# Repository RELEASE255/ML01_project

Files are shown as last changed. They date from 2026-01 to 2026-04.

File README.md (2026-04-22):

# ML01 project by Greg
**DIY LED Board Powered by Raspberry Pico 2W**







<p align="center">
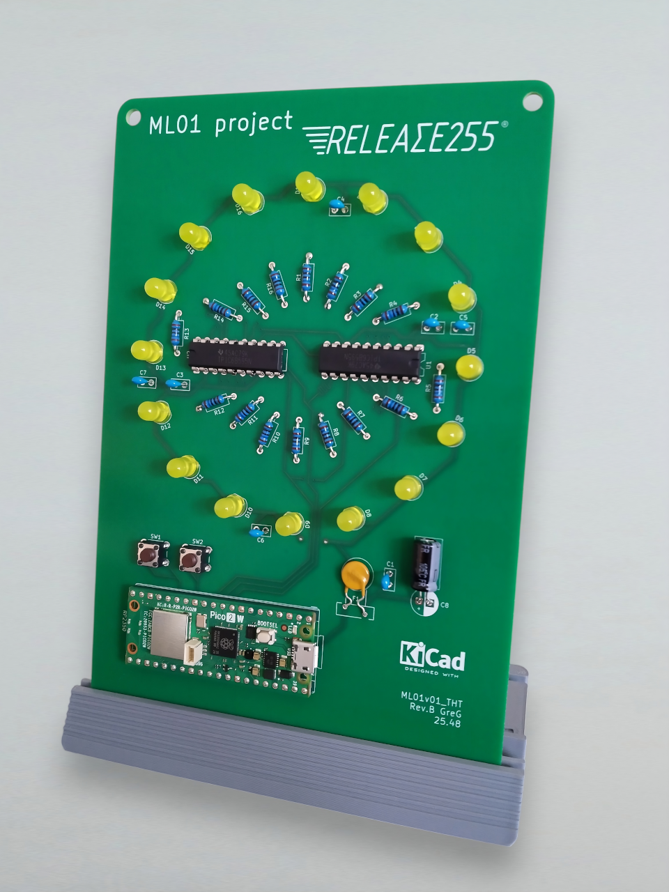
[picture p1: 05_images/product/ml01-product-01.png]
<br>
<sub>ML01 Main image</sub>
</p>

---

# 💡 Overview

**ML01** is a fully DIY through-hole LED board driven by a **Raspberry Pi Pico 2W** and two **TPIC6B595** shift registers. Built for makers, learners, and electronic enthusiasts, this product combining:

- Electronics learning
- Soldering practice
- Microcontroller programming
- Wireless control via Microdot
- Possibility to customize the firmware and hardware
- Open hardware philosophy with protected PCB design

---

# 📋 Key Features

- **LED Circle** | 16 yellow LEDs driven by 2× TPIC power shift registers
- **Physical Controls** | 2 buttons to switch operating modes
- **Wireless Web Interface** | Autonomous Microdot server for full remote control
- **Mode 1 (FULL)** | Turn all LEDs on 
- **Mode 2 (CHASE)** | Minute indicator synchronized via an NTP server
- **100% DIY THT** | Perfect for beginners and maker who wish to assemble or repair their product
- **Upgradable Firmware** | New modes and features can be added anytime
- **Easy Powered** | Works with the included 12.5 W PSU or via USB
- **Budget Friendly** | Transparent and moderate costs coupled with low consumption (~1 Wh)

---

# 📦 Contents of the Kit

**Available on Tindie (coming soon):**
- 01x PCB  

**To be purchased separately:**
- 01x Raspberry Pi Pico 2W (THT version)
- 01x Raspberry power supply 12.5 W (5.1 V / 2.5 A)
- 02x TPIC6B595 (Power Shift Register)
- 16x Yellow LED (2500 mcd 60 deg)
- 16x Metal resistors 160Ω 
- 07x Ceramic capacitor (X7R 100 nF)
- 01x Electro radial capacitor (100µF)
- 01x Resettable fuse
- 02x Push buttons  

**To be printed according to the provided 3D model:**
- 01x PCB stand
<br>

<p align="center">
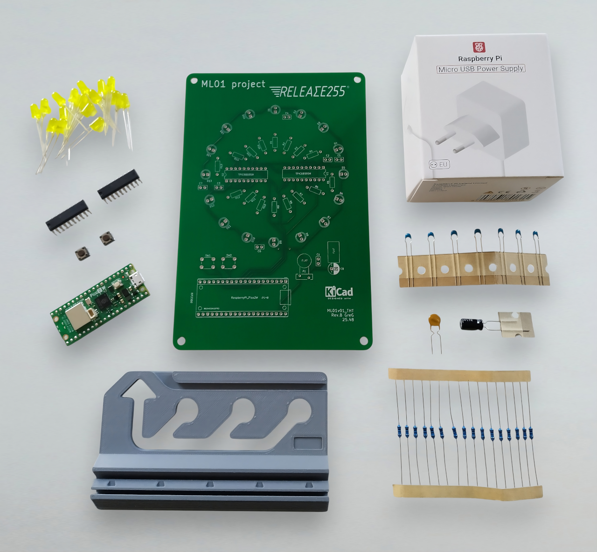
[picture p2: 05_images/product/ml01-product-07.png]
<br>
<sub>Complete DIY kit packaging</sub>
</p>

---

# 📸 Gallery

<p align="center">
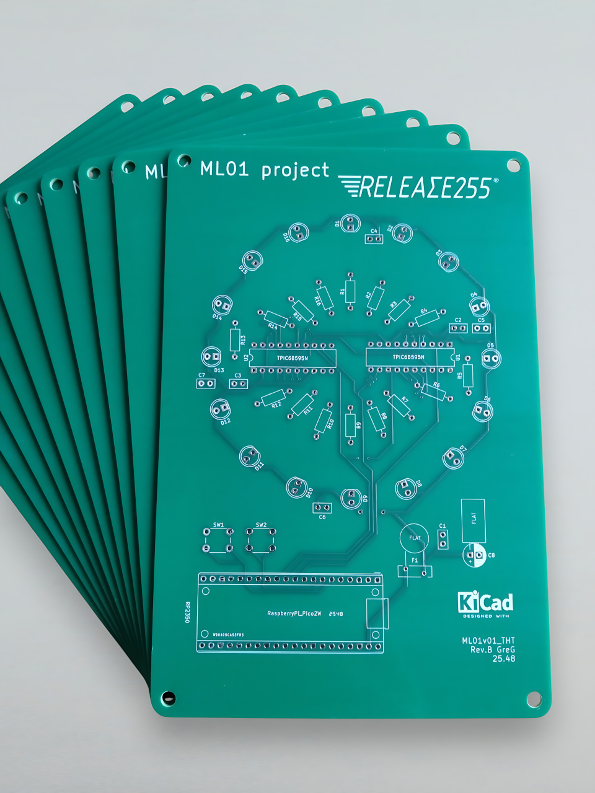
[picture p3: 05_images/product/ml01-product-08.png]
  <br>
<sub>Bare PCB front view</sub>
</p>

<p align="center">
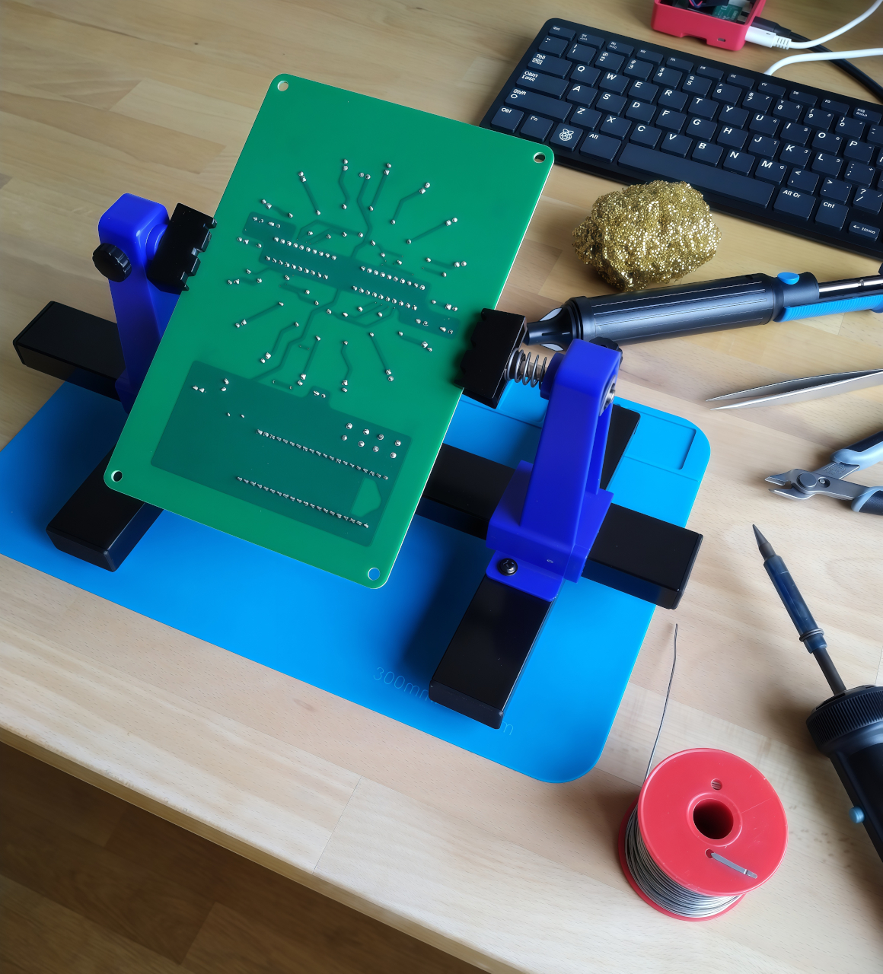
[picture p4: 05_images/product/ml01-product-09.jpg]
  <br>
<sub>DIY soldering THT components</sub>
</p>

<p align="center">
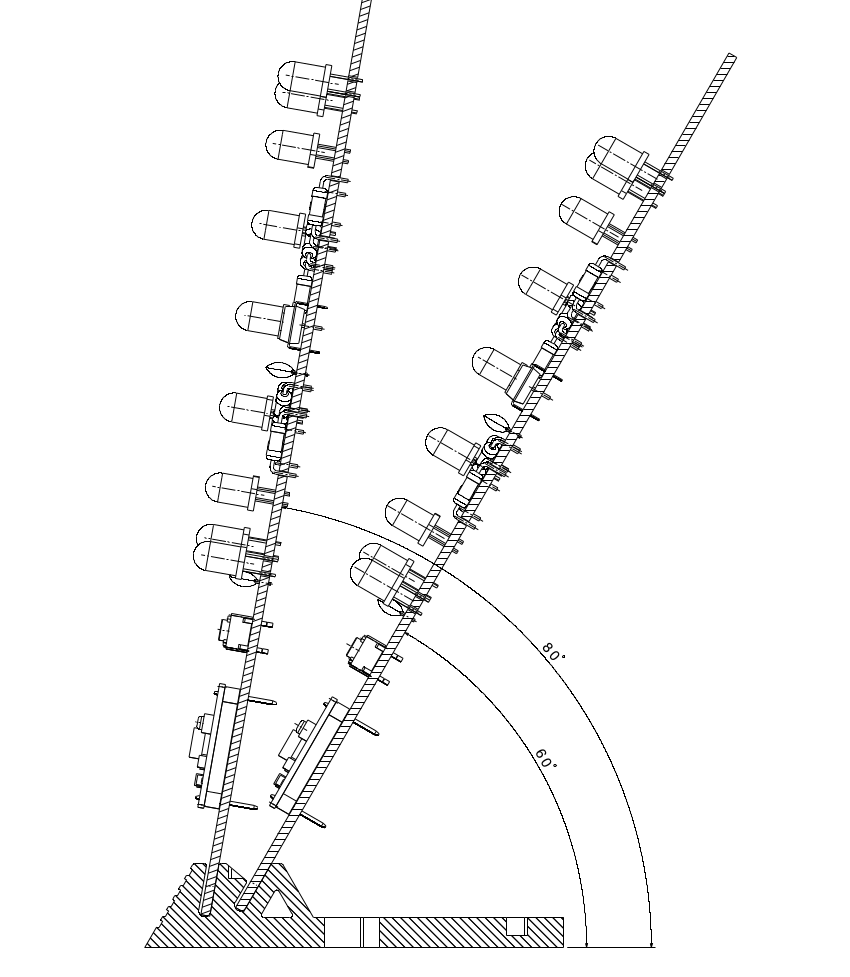
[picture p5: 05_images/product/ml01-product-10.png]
  <br>
<sub>Choice of orientation on the stand</sub>
</p>

<p align="center">
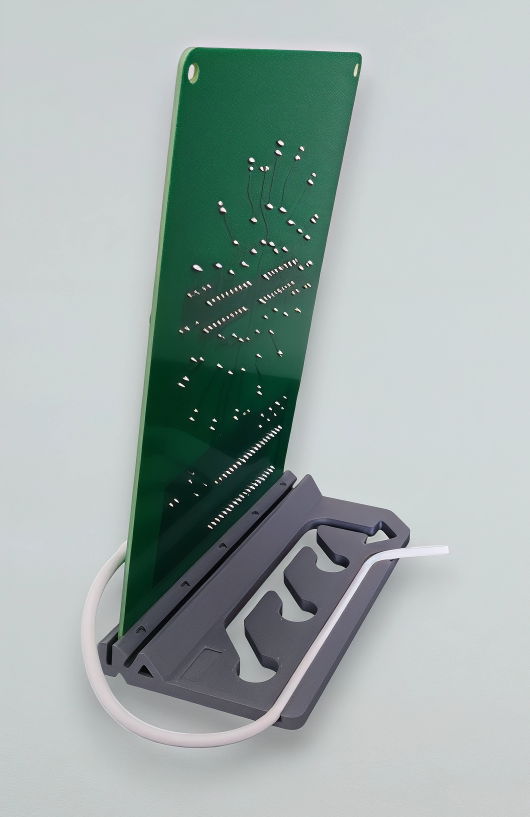
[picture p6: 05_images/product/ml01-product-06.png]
  <br>
<sub>PCB stand with cable holding</sub>
</p>

<p align="center">
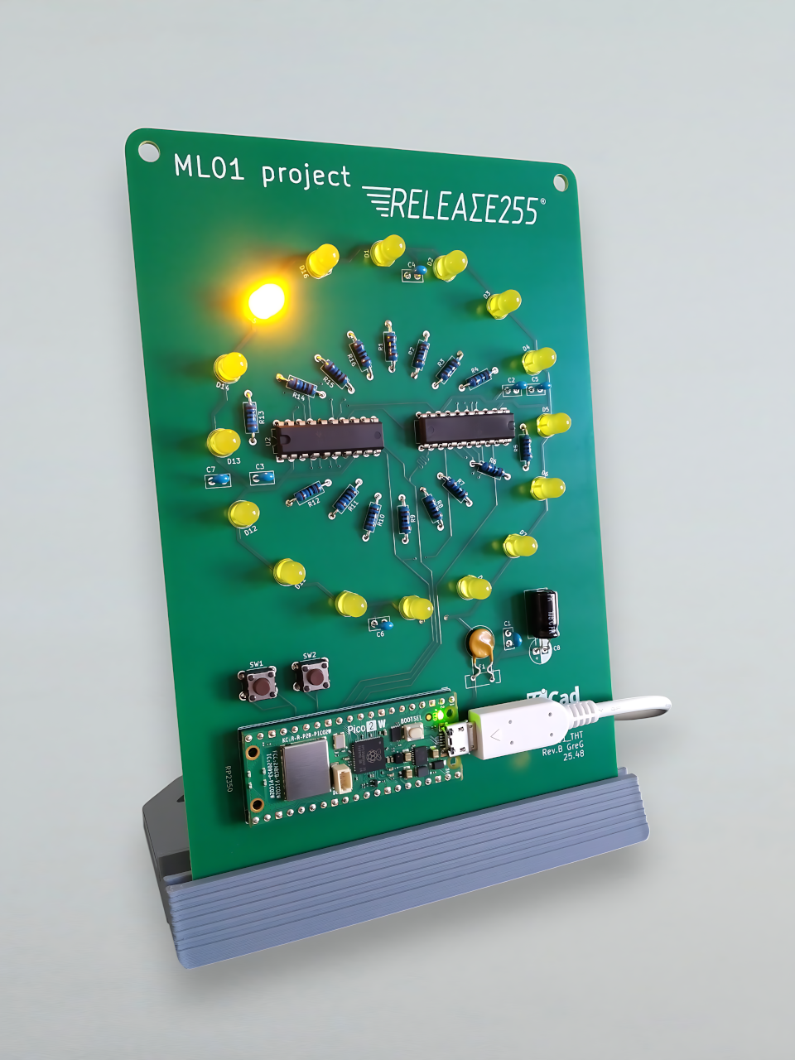
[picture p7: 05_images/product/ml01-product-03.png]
  <br>
<sub>CHASE mode activated</sub>
</p>

<p align="center">
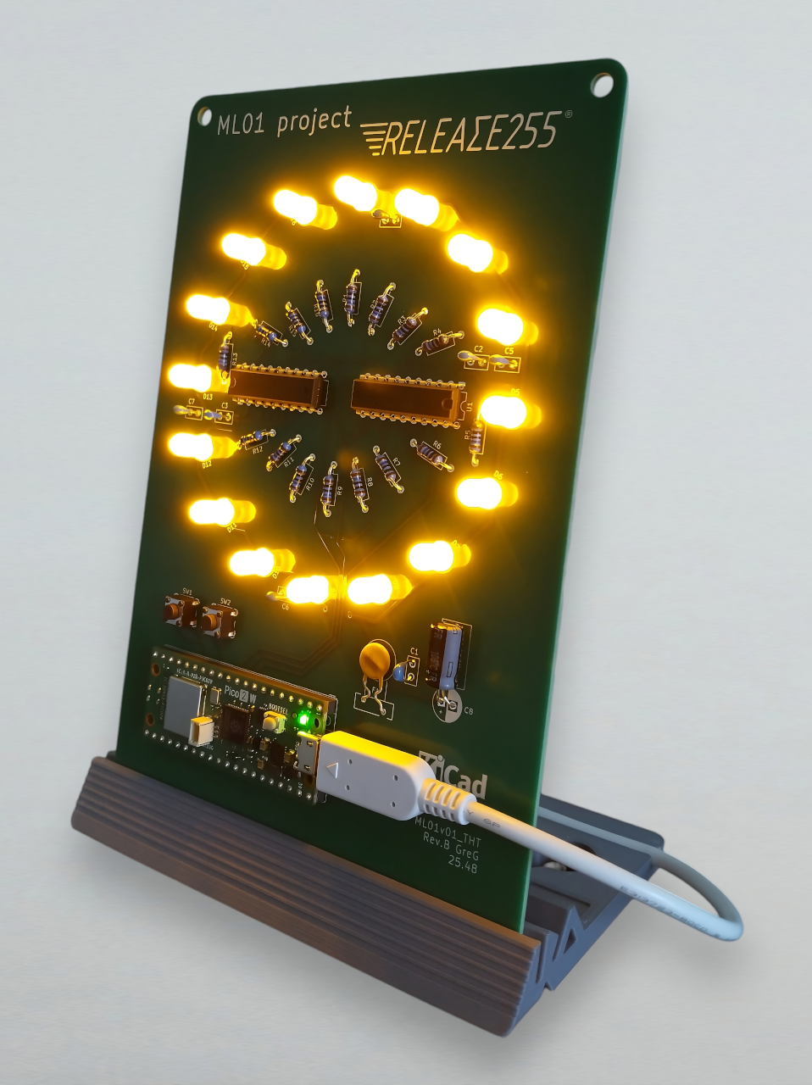
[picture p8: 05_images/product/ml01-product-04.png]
  <br>
<sub>FULL mode activated</sub>
</p>

<p align="center">
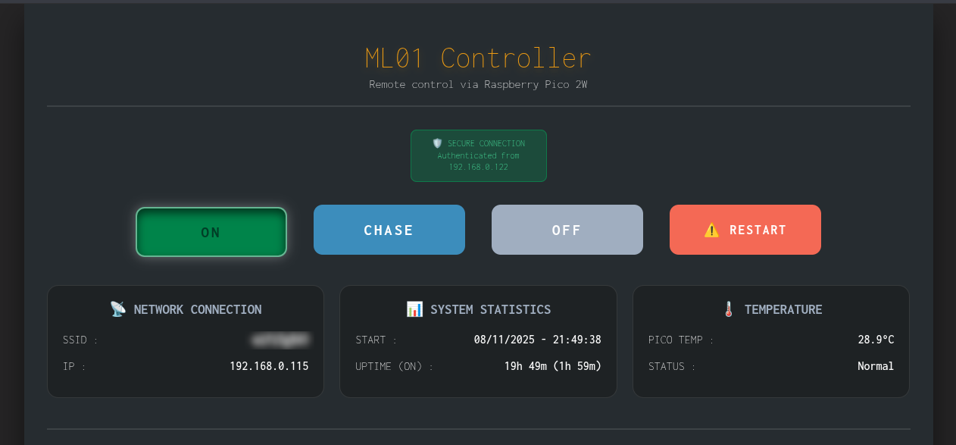
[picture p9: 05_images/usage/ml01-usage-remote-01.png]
  <br>
<sub>Web interface for remote control</sub>
</p>

<p align="center">
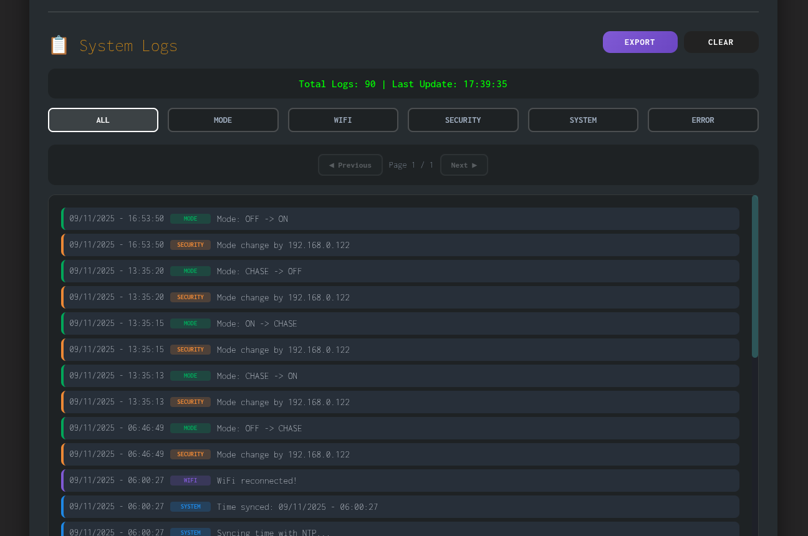
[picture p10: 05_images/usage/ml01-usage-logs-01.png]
  <br>
<sub>Web interface for log monitoring</sub>
</p>

<p align="center">
  ML01 CHASE mode animation<br>
  <sub>CHASE mode animated</sub>
</p>

---

# 📚 Documentation

## Specifications
See the document [Specifications](01_docs/ML01-specifications.md)

## Quick Start
1. **Solder** all components following the guide (⏱️ ~ 5 hours)
2. **Finishing** the PCB assembly with the cleaning
3. **Flash** the firmware to your Pico 2W
4. **Configure** the main.py file as you wish
5. **Transfer** the 3 files (main.py, index.html, microdot.py) to your pico
6. **Plug** the device to start the programm, it connects to your WiFi network
7. **Control** via web interface or the buttons

## Assembly  
Follow the complet guide to [Assembly](01_docs/ML01-assembly.md)

## Configuration  
Follow the complet guide to edit [Settings](01_docs/ML01-settings.md)

## Control & consult logs
Using the 2 physical buttons or the web interface, see the document [Usage](01_docs/ML01-usage.md)

---

# ⚠️ Disclaimer

- This is a **DIY kit requiring soldering**
- Assembly mistakes may damage components
- No warranty is provided
- Use at your own risk
- This device is intended for personal, non-commercial use only
  
**It has not been tested or certified to meet:**
- CE electromagnetic compatibility standards
- FCC Part 15 regulations
- RoHS compliance (components should be RoHS-compliant when sourced)

---

# 🌐 Ecosystem

- **3d stand:** *https://www.printables.com/model/1552197-pcb-stand*

# 💶 Buy the PCB

Feel free to contact me if this project interests you and you would like to purchase the printed circuit board.

---

# 📜 License Overview

ML01 uses a **multi-license** & **balanced open source model.**  
The main license is MIT but other parts of the project use Creative Commons licenses.  
Below is the complete list of licenses used in the repository.  
If you have any question about licensing or permitted uses, contact the project maintainer.

| Category | License | File Types | Commercial use | Full text |
|---|---|---|---|---|
| Firmware | MIT | `.py` `.html` | ✅ Allowed | [LICENSE](LICENSE) |
| BOM | CC BY-SA 4.0 | `.pdf` | ✅ Allowed | [LICENSE](03_hardware/LICENSE-bom.md) |
| Documentation | CC BY-NC-SA 4.0 | `.pdf` `.md` | 🚫 Not allowed | [LICENSE](01_docs/LICENSE-docs.md) |
| Technical plans | CC BY-NC-SA 4.0 | `.pdf` | 🚫 Not allowed | [LICENSE](03_hardware/LICENSE-hardware.md) |
| Schematics | CC BY-NC-SA 4.0 | `.pdf` | 🚫 Not allowed | [LICENSE](03_hardware/LICENSE-hardware.md) |
| 3D Models | CC BY-NC-SA 4.0 | `.stl` `.stp` | 🚫 Not allowed | [LICENSE](04_3dmodels/LICENSE-3dmodels.md) |
| Images | CC BY-NC-SA 4.0 | `.png` `.jpg` | 🚫 Not allowed | [LICENSE](05_images/LICENSE-images.md) |
| PCB Sources | Proprietary | Kicad & Gerbers | ❌ Not available | N/A |

### 🔒 PCB sources remain proprietary

In order to preserve the value of the design, guarantee independence, sustainability and the protection of creators, the following elements are not available:

- KiCad source files
- PCB routing & layout
- Gerber files
- 3D model of the actual PCB

### Third-Party Dependencies and Licenses

The ML01 firmware uses two essential external components:

#### **MicroPython**
ML01 runs on MicroPython, a Python interpreter optimized for microcontrollers.
- **License MIT**
- **Author:** Damien P. George and contributors
- **Official website:** https://micropython.org
- **Full text license:** [here](02_firmware/LICENSE-micropython.md)  
ℹ️ The firmware provided in this repository may not necessarily be the latest version.

#### **Microdot**
Microdot is an ultra-lightweight web micro-framework used for the ML01 kit's HTML interface.
- **License MIT**
- **Author:** Miguel Grinberg
- **Official Repository:** https://github.com/miguelgrinberg/microdot
- **Full text license:** [here](02_firmware/LICENSE-microdot.md)  
ℹ️ The `microdot.py` file provided in this repository may not necessarily be the latest version.

---

# 🤝 Contributions & Collaboration

Contributions to the **firmware** and **documentation** are welcome!

- Open issues for bugs, ideas, or improvements
- Submit pull requests for code or docs
- Proprietary files cannot be modified

### Interested in partnering?
I'm open to collaborations with:

- Makers
- Hardware designers
- Open-source communities

Let's explore cross-promotion, joint tutorials, shared tools, or group orders.

---

# 🗂️ Repository Structure

```
ML01/
├── 01_docs/
│   ├── LICENSE-docs.md
│   ├── ML01-assembly.md
│   ├── ML01-costs.pdf
│   ├── ML01-settings.md
│   ├── ML01-specifications.md
│   └── ML01-usage.md
│
├── 02_firmware/
│   ├── LICENSE-firmware.md
│   ├── LICENSE-microdot.md
│   ├── LICENSE-micropython.md
│   ├── RPI_PICO2_W-YYYYMMDD-vX.XX.X.uf2
│   ├── index.html
│   ├── main.py
│   └── microdot.py
│
├── 03_hardware/
│   ├── LICENSE-bom.md
│   ├── LICENSE-hardware.md
│   ├── ML01-bom.pdf
│   ├── ML01-drawingA3.pdf
│   └── ML01-kicad-schematic.pdf
│
├── 04_3dmodels/
│   ├── LICENSE-3dmodels.md
│   ├── ML01-pcbstand-v01.stl
│   └── ML01-pcbstand-v01.stp
│
├── 05_images/
│   ├── assembly/
│   ├── product/
│   ├── settings/
│   ├── usage/
│   └── LICENSE-images.md
│
├── CHANGELOG.md
├── CONTRIBUTING.md
├── LICENSE
└── README.md
```

*Revision date: 2026.04.22*<br>
© ML01 project by Greg | All rights reserved

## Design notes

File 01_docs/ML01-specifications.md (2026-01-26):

# ML01 PROJECT – SPECIFICATIONS
The ML01 project is an electronic system based on a **Raspberry Pi Pico 2W**.  
Its main role is to control **16 yellow LEDs** using 2 buttons and a lightweight embedded web interface using the Microdot framework.  
All components are Through-Hole Technology (THT) and require assembly onto a printed circuit board (DIY).  
<br>
⚠️ **LIMITATIONS AND WARNINGS** ⚠️
- **Indoor use only**
- **Not CE/FCC certified** | Hobbyist/educational use only
- **DIY assembly required** | Soldering skills necessary
- **Open PCB design** | Avoid contact with conductive materials
- **ESD sensitive** | Handle with antistatic precautions
- **No over-voltage protection** beyond PTC fuse
- **Wi-Fi stability** depends on local environment and interference
- **Safety Precautions while the device is powered:** thank you for reading the details at the end of this document.

**The following guides are provided in separate documentation files:**
- 📖 [ASSEMBLY guide](../01_docs/ML01-assembly.md)  
- 📖 [SETTINGS guide](../01_docs/ML01-settings.md)  
- 📖 [USAGE guide](../01_docs/ML01-usage.md)
---

## A. FUNCTIONS
### A1. LED modes by default
- **FULL mode:** all 16 LEDs ON continuously
- **CHASE mode:** dynamic LED animation sequence synchromnized with Time NTP server
- **OFF mode:** all LEDs OFF  
- **OTHER modes:** also you could completely reprogram the microcontroller according to your needs.

### A2. User Button Actions
**Button 1:**
- **Short press:** cycle through modes → FULL → CHASE → OFF
- **Long press:** stop script execution

**Button 2:**
- **Long press:** system reboot

### A3. Web Interface (Microdot):
- Lightweight HTTP server running on Raspberry Pi Pico 2W
- Default port: **5000**
- Provides remote access to LED modes, system status, and log viewing-exporting
- Requires Wi-Fi connection (SSID/password configured in firmware)
---

## B. HARDWARE
### B1. Main Controller: 1× Raspberry Pi Pico 2W RP2350 (THT variant)
- Handles GPIO control, timing, LED driving logic, and web server
- Powered via VSYS (pin 39) from external PSU or USB

### B2. Output Driving: 2× TPIC6B595N power shift registers
- 8 open-drain DMOS outputs per chip
- Up to 150 mA continuous current per output
- Daisy-chain capable (SER OUT → SER IN)
- VCC: +5V, logic-compatible with 3.3V GPIO

### B3. Optoelectronics: 16× yellow LEDs
- High efficiency
- Low power consumption
- Dimension: 5mm round standard
- Brightness: 2500 mcd typical
- Viewing angle: 60°
- Forward voltage: 1.9 to 2.3V typical
- Maximum forward current: 30 mA

### B4. User Input: 2× push buttons (6×6 mm, 1.6 N travel)
- Button 1: GPIO 4
- Button 2: GPIO 5
- Internal pull-ups enabled in firmware

### B5. Power Conditioning
**16× 160 Ω metal-film resistors (1% 0.6 W):** current limiting for LEDs (~18 mA per LED)

**7× 100 nF ceramic capacitors (X7R, 10% tolerance):**
- 1× per TPIC6B595N
- 4× near LED clusters
- 1× parallel to main electrolytic capacitor

**1× 100 µF electrolytic capacitor (Ø6.30 mm, H11.20 mm):** main power input filtering (+5V to GND)

**1× resettable PTC fuse (Bourns MF-R050):**
- Hold current: 0.5 A
- Trip current: 1.0 A
- Max voltage: 30 V
- Power rating: 750 mW
- Resistance: 770 mΩ

### B6. Power Input
| PARAMETER | VALUE |
|---|---|
| Voltage | 5 V DC |
| Current (FULL mode) | ~260 mA (1.3 W) |
| Current (OFF mode)  | ~35 mA (0.18 W) |
| Protection | PTC resettable fuse (0.5 A hold / 1 A trip) |

### B7. Power Supply: 1x Raspberry Pi 12.7W Micro USB
- AC 100-240V 50/60Hz input
- DC 5.1V 2.5A output
- 12.7W maximum output power
- 1.5m 18AWG captive cable
- Micro USB output connector
- Can alternatively be powered via USB port from computer.

### B8. LED Driving
- Open-drain low-side switching via TPIC6B595
- LED anodes connected to +5 V
- LED cathodes connected to TPIC DRAIN outputs through 160 Ω resistors
- LED current per channel: ~18 mA @ 5V supply
- Calculation: (5V - 2.1V Vf) / 160Ω ≈ 18 mA

### B9. Decoupling Strategy
- 1x 100 nF ceramic capacitor on each TPIC6B595N (VCC to GND)
- 4× 100 nF ceramic capacitors distributed near LED clusters
- 1× 100 nF ceramic capacitor in parallel with electrolytic capacitor at main power input
- 1x 100 µF electrolytic capacitor in parallel with ceramic capacitor at main power input

### B10. PCB Specifications
| PROPERTY | VALUE |
|---|---|
| Dimensions | 165 × 110 mm |
| Thickness | 1.6 mm |
| Layer Count | 2 |
| Copper Weight | 1 oz (35 µm) |
| Surface Finish | HASL lead-free |
| Solder Mask Color  | Green |
| Component Mounting | Through-Hole (THT) |
---

## C. WIRING
### C1. GPIO Pin Mapping for Raspberry Pi Pico 2W
| GPIO PIN | FUNCTION | CONNECTION |
|---|---|---|
| GPIO 4 | Button 1 Input | Push button (active LOW) |
| GPIO 5 | Button 2 Input | Push button (active LOW) |
| GPIO 7 | TPIC SER IN | Serial data to first TPIC |
| GPIO 8 | TPIC RCK | Register clock (both) |
| GPIO 9 | TPIC SRCK | Shift register clock (both) |

### C2. TPIC6B595N Pin Mapping
**First TPIC (chain input):**
| PIN | CONNECTION |
|---|---|
| Pin 1, 20 | Not used |
| Pin 2 (VCC) | +5V (Pico pin 39, VSYS) |
| Pin 3 (SER IN) | Pico GPIO 7 |
| Pins 4-7(DRAIN 0-3) | LED cathodes via 160Ω resistors |
| Pin 8 (SRCLR) | +5V (reset disabled, always HIGH) |
| Pin 9 (G) | GND (outputs always enabled, active LOW) |
| Pin 10, 11, 19 (GND) | Pico GND (pin 3) |
| Pin 12 (RCK) | Pico GPIO 8 |
| Pin 13 (SRCK) | Pico GPIO 9 |
| Pins 14-17 (DRAIN 4-7) | LED cathodes via 160Ω resistors |
| Pin 18 (SER OUT) | Pin 3 (SER IN) of second TPIC |

**Second TPIC (chain output):**  
Same connections as first TPIC apart from the differences below:
- Pin 3 (SER IN) ← Pin 18 (SER OUT) of first TPIC
- Pin 18 (SER OUT) → not connected

### C3. LEDs Connections
- **LED anodes** → +5 V (common rail)
- **LED cathodes** → TPIC DRAIN outputs via 160 Ω resistor

### C4. Buttons Connections
- **Button 1** → One pin to GPIO 4 (Pico pin 6), other pin to GND
- **Button 2** → One pin to GPIO 5 (Pico pin 7), other pin to GND
- Internal pull-up resistors enabled in firmware (buttons active LOW)
---

## D. SOFTWARE
### D1. Firmware (MicroPython for Raspberry Pi Pico 2W RP2350)
- Download last version UF2 bootloader image [here](https://micropython.org/download/RPI_PICO2_W/)
- Flash via USB mass storage mode

### D2. Program Structure
- `main.py`: main control program, download last version [here](../02_firmware/)
- `index.html`: web interface for remote control and log viewing/exporting, download last version [here](../02_firmware/)
- `microdot.py` : lightweight web server, download last version [here](https://github.com/miguelgrinberg/microdot)

### D3. Dependencies and References
- [Raspberry Pi Pico 2W](https://www.raspberrypi.com/documentation/microcontrollers/)
- [TPIC6B595N Datasheet](https://www.ti.com/lit/ds/symlink/tpic6b595.pdf)
- [MicroPython](https://docs.micropython.org/en/latest/)
- [Microdot](https://microdot.readthedocs.io/en/latest/index.html#)
---

## E. ENCLOSURE CONSIDERATIONS (to be printed according to provided 3D files)
**This is an open PCB design:**
- The PCB stand allows 2 possible tilt angles: 80° and 60°.
- The PCB stand must be printed according to the file provided on this repo [here](../04_3dmodels/) or Printables [here](https://www.printables.com/model/1552197-pcb-stand)
- The ML01 project deliberately does not include a fully enclosed protective case at this stage.
- This design choice allows all electronic components to remain visible, which is valuable for:  
        - Educational purposes and learning electronics<br>
        - Demonstrating the circuit layout and component placement<br>
        - Aesthetic appreciation of the assembled board

⚠️ **Safety Precautions while the device is powered:**
- **Do NOT touch** any part of the PCB except the two push buttons
- Risk of **electric shock** from exposed 5V circuitry
- Risk of **short circuits** causing component damage or failure
- Risk of **ESD damage** to sensitive components (Pico 2W, TPICs)

**This device is fragile:**
- Solder joints and component leads can break with rough handling
- Through-hole components are more robust than SMD but still require care
- Use the provided 3D-printed stand to minimize handling

**Indoor use only:**
- Indoor use in dry, controlled environments (typical household/office: 30–60% RH)
- Not rated for outdoor or humid environments (no conformal coating)
- Keep away from water, liquids, and excessive moisture
- Avoid dusty or dirty environments that could cause short circuits

**Recommended operating environment:**
- Recommended ambient: 15–30°C for optimal long-term reliability (mini 0°C to max 70°C)
- Keep away from direct sunlight to prevent overheating
- Workbench or desk in a clean (avoid directly on the ground)
- Display area with controlled access (away from children and pets)

**Future Enclosure Options:**
- A protective enclosure may be offered in future revisions of this project if the need is actually confirmed.
- Users who require additional protection may design their own enclosure, ensuring adequate ventilation for heat dissipation.
---

## F. COMPLIANCE AND STANDARDS
This device is intended for personal, non-commercial use only.  
Users are responsible for ensuring compliance with local regulations if used in any commercial capacity.  
<br>
**It has not been tested or certified to meet:**
- CE electromagnetic compatibility standards
- FCC Part 15 regulations
- RoHS compliance (components should be RoHS-compliant when sourced)
---

*Revision date: 2026.01.26*<br>
© RELEASE255 | All rights reserved

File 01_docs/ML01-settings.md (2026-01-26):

# ML01 PROJECT – SETTINGS GUIDE
This document guides you through the firmware installation and initial configuration of your ML01 device.

## A. PREREQUISITES
Before starting, ensure you have:  
✓ Fully assembled ML01 PCB (see 📖 [ASSEMBLY](../01_docs/ML01-assembly.md))  
✓ Micro-USB cable  
✓ 5.1V 2.5A power supply (for standalone operation after setup)  
✓ Computer running Linux, Windows, or macOS  
✓ Integrated development environment (IDE) such as Thonny with MicroPython interpreter  
✓ Internet connection (note that the Pico 2W is only compatible with a **2.4 GHz Wi-Fi network**)  
✓ Wi-Fi network with known SSID and password  
✓ Your computer's local IP address (instructions below)
###
---

## B. FLASH MICROPYTHON FIRMWARE TO RASPBERRY PICO 2W
⚠️ **This step is required before first use**
### B1. Download Firmware
- **01.** Visit https://micropython.org/download/RPI_PICO2_W/
- **02.** Download the latest stable release `.uf2` file.

### B2. Enter Bootloader Mode & Flash Firmware
- **01.** Locate the **BOOTSEL button** on the Raspberry Pi Pico 2W (small white button near the micro-USB connector).
- **02.** **Push and hold** the BOOTSEL button while connecting your Pico with a USB cable to your computer.
- **03.** **Release** the BOOTSEL button **once your Pico appears as a Mass Storage Device.**
- **04.** **Drag and drop** the MicroPython UF2 file onto the RPI-RP2 volume, your Pico will **automatically reboot.**
- **05.** **Wait** for the process to complete (~5 seconds).

### B3. Verify Firmware Installation
- **01.** **Disconnect** the Pico from your computer.
- **02.** **Reconnect** the Pico via micro-USB.
- **03.** Open your **IDE**.
- **04.** Make sure the Pico is recognized:  
        - With Thonny, check bottom-right corner.<br>
        - Should see "MicroPython (Raspberry Pi Pico)"<br>
        - If not, click the interpreter selector and choose it.<br>
- **05.** You should see the instructions below in the shell using Thonny editor:

<p align="center">
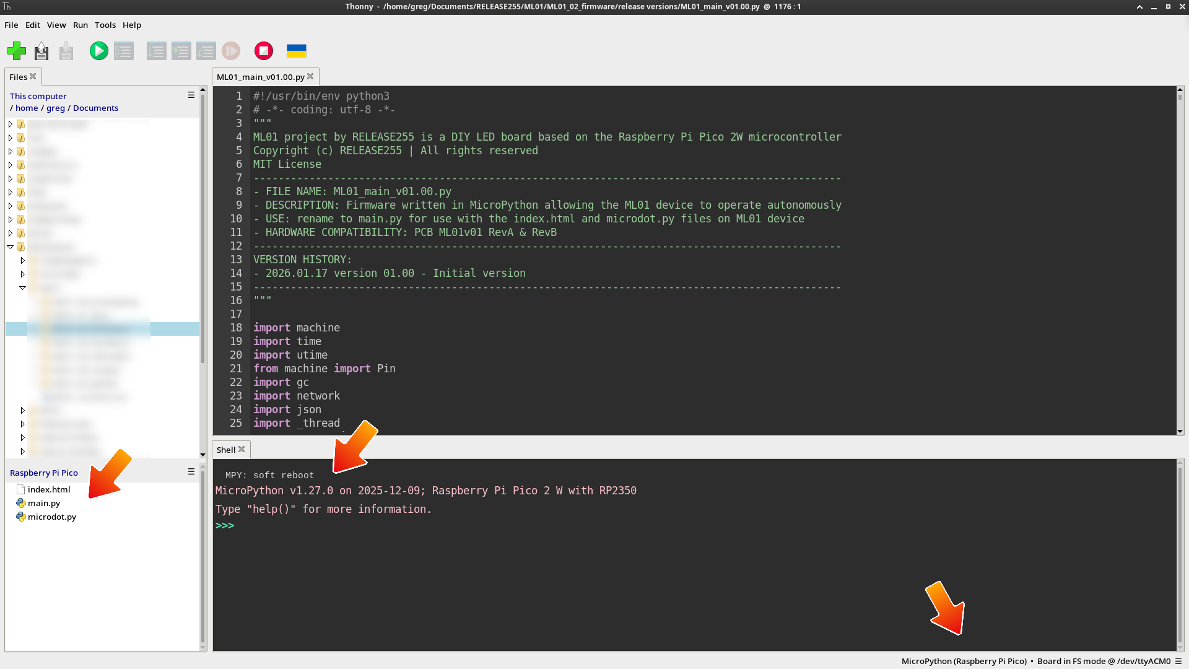
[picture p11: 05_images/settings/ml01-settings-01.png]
  
</p>

✅ **Firmware installation successful!**
###
---

## C. DOWNLOAD FIRMWARE FILES FROM GITHUB
Download the following three files from the `02_firmware/` folder [here](../02_firmware/):

```
02_firmware/
├── index.html      ← Web interface HTML file
├── main.py         ← Main control program
└── microdot.py     ← Lightweight web server library
```
---

## D. CONFIGURE main.py FILE
The `main.py` file contains all configuration parameters for your ML01 device.
### D1. Open main.py in Thonny
- **01.** In Thonny, click **File → Open...**
- **02.** Navigate to where you saved the firmware files.
- **03.** Open **main.py**.

### D2. Locate Configuration Section
- **01.** Press **Ctrl+F** (Windows/Linux) or **Cmd+F** (macOS) to open Find.
- **02.** Search for: `# CONFIGURATION`
- **03.** You should find the configuration section around **line 37** (may vary slightly):

<p align="center">
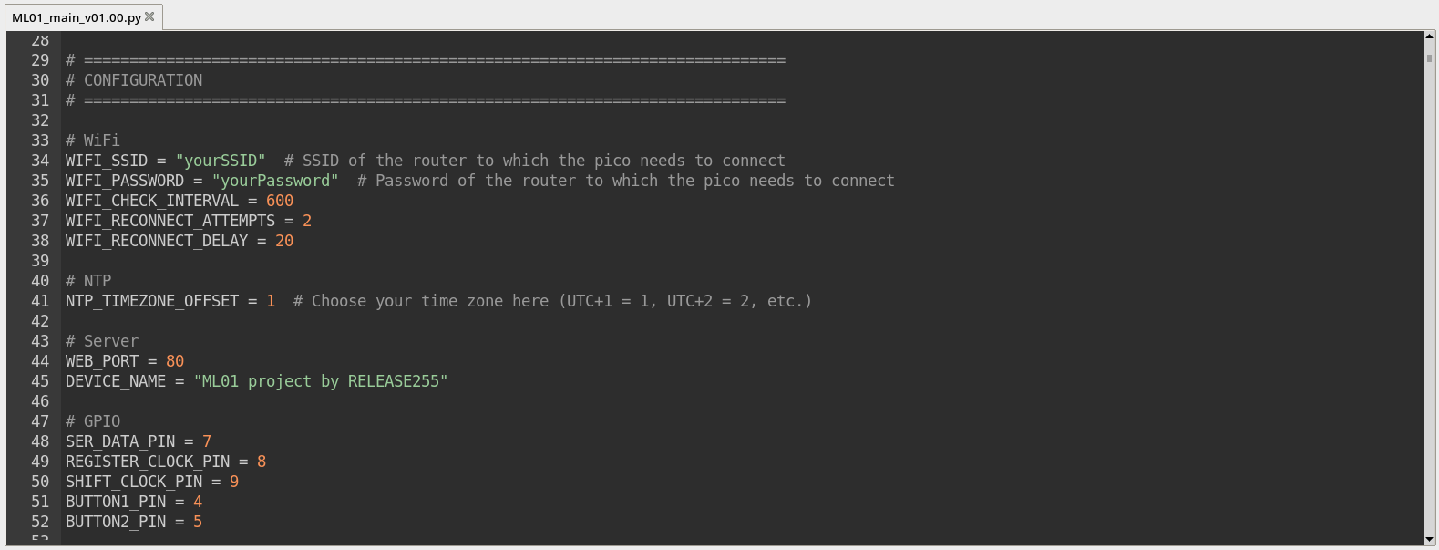
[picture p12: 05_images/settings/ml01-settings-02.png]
  
</p>

### D3. Configure Wi-Fi Settings
Locate the **WiFi** section:
```python
# WiFi
WIFI_SSID = "yourSSID"
WIFI_PASSWORD = "yourPassword"
```
- **01.** Replace `"yourSSID"` with your Wi-Fi network name.
- **02.** Replace `"yourPassword"` with your Wi-Fi password.

### D4. Configure Timezone (NTP)
Locate the **NTP** section:
```python
# NTP
NTP_TIMEZONE_OFFSET = 1
```
**Set your timezone offset relative to UTC, for example:**
| Location | Offset | Value |
|---|---|---|
| Seoul | UTC+9  | `9` |
| Taipei | UTC+8  | `8` |
| Bengaluru | UTC+5  | `5` |
| Zurich | UTC+1  | `1` |
| London | UTC+0  | `0` |
| Boston | UTC-5  | `-5`  |
| Palo Alto | UTC-8  | `-8`  |

**Note:** This does not account for Daylight Saving Time (DST). Adjust manually if needed.

### D5. Configure LED Timing (Optional)
Locate the **Timing** section:

<p align="center">
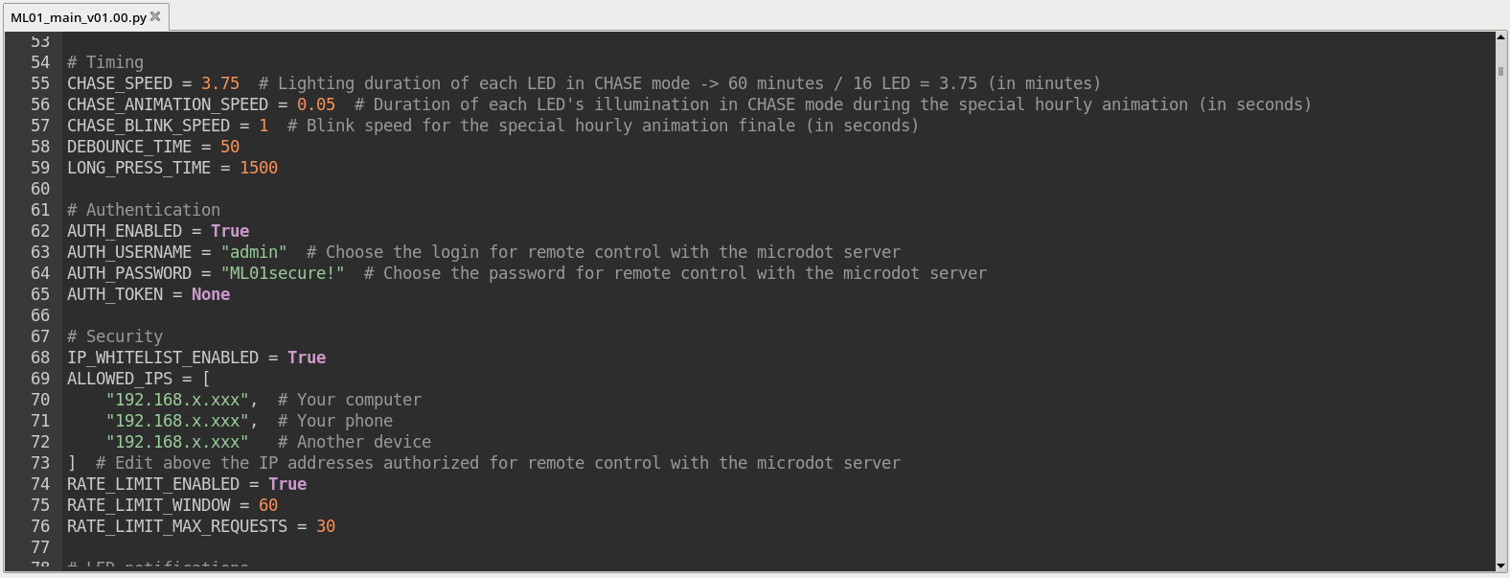
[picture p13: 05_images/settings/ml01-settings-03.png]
  
</p>

- **01.** `CHASE_ANIMATION_SPEED`: Adjust the value as needed  
        - Default: `0.05` (50ms per LED)
        - Lower = faster animation
        - Higher = slower animation
- **02.** `CHASE_BLINK_SPEED`: Adjust the value as needed  
        - Default: `1` (1 second on/off cycle)

### D6. Configure Web Authentication
Locate the **Authentication** section:
- **01.** `AUTH_ENABLED`: Controls whether web interface requires login.  
        - `True` = Login required (recommended)
        - `False` = Open access (not recommended on shared networks)
- **02.** `AUTH_USERNAME`: Choose a username for web interface access.  
        - Default `AUTH_USERNAME = "admin"`
- **03.** `AUTH_PASSWORD`: Choose a secure password for web interface access.  
        - Default `AUTH_PASSWORD = "ML01secure!"`

### D7. Configure IP Address Whitelist
Locate the **Security** section:  
```python
ALLOWED_IPS = [
    "192.168.1.100",  # Your computer
    "192.168.1.105",  # Your phone
    "192.168.1.110"   # Another device
]
```
- Find your computer's local IP address and replace placeholder IPs with actual addresses you want to allow.
- **Purpose:** Restricts web interface access to specific IP addresses on your local network.
- To disable IP filtering entirely **(not recommended):** set `AUTH_ENABLED = False`

⚠️ **Security Recommendation:**  
✓ Change default `AUTH_USERNAME` and `AUTH_PASSWORD`.  
✓ Use strong passwords (mix of letters, numbers, symbols).  
✓ Keep `AUTH_ENABLED = True` on shared networks.  
✓ Update `ALLOWED_IPS` if your network changes (DHCP).  
✓ Consider setting **static IP** for your devices in router settings.  
✓ If `AUTH_ENABLED = True` and `ALLOWED_IPS = []` (empty list), **no devices can connect**.  
✓ Do not expose Pico to public internet without additional security measures.  
✓ Regularly update MicroPython firmware for security patches.
###

### D8. Save Configuration
- **01.** Review all changes carefully.
- **02.** In Thonny, click **File → Save** (or press **Ctrl+S** / **Cmd+S**).
- **03.** Keep the file open in Thonny for the next step.
---

## E. UPLOAD FILES TO RASPBERRY PI PICO
### E1. Connect Pico to Computer
Connect your Raspberry Pi Pico 2W to your computer via micro-USB cable (if it hasn't already been done).

### E2. Upload main.py
- **01.** With `main.py` open and configured in Thonny, click **File → Save As...**
- **02.** In the dialog, select **"Raspberry Pi Pico"** as the destination.
- **03.** Name exactly the file: **`main.py`** (allows the program to start automatically when the Pico is connected to the power supply).
- **04.** Click **OK** to upload.

### E3. Upload microdot.py
Do the same thing as before, saving the **`microdot.py`** file in the pico

### E4. Upload index.html
Do the same thing as before, saving the **`index.html`** file in the pico

### E5. Verify Files on Pico
- **01.** In Thonny, look at the **Files panel** (usually on the left side).
- **02.** Under **"Raspberry Pi Pico"**, you should see:
```
/
├── index.html
├── main.py
└── microdot.py
```

<p align="center">
  
</p>

✅ **All files successfully uploaded!**
###
---

## F. VERIFY INSTALLATION
### F1. Run Initial Test
- **01.** In Thonny, ensure the **`main.py`** tab is active.
- **02.** Click the **green "Run" button** (▶) or press **F5**.
- **03.** Monitor the **Shell panel** at the bottom of Thonny.

### F2. Check Console Output
You should see output similar to:
```
======================================================================
ML01 LED CONTROLLER - PICO 2W
======================================================================

MODES:
• OFF: All LEDs off
• ON: All LEDs on
• CHASE: Sequential LED movement

CONTROLS:
• Button 1 short: Switch mode
• Button 1 long: Shutdown
• Button 2 long: Manual restart
• Web: http://[IP_ADDRESS]

LED NOTIFICATIONS:
• Solid: WiFi connected
• OFF: WiFi disconnected
• Fast blink: New connection
----------------------------------------------------------------------

Initializing security...
[SYSTEM] Auth enabled (user: admin)
✓ Auth: admin
✓ IP filter: 6 allowed
✓ Rate limit: 30/60s
Initializing GPIO...
GPIO initialized
[SYSTEM] ML01 Controller started
Connecting to WiFi...
[SYSTEM] Syncing time with NTP...
[SYSTEM] Time synced: 31/12/2025 - 09:19:46
✓ Time synced (UTC+1)
[SYSTEM] Start time updated after NTP
Starting web server thread...
[WEB] Thread started
[WEB] Free memory: 402880 bytes
[WEB] Starting on port 80...
[WEB] http://192.168.0.124:80
[SYSTEM] Web server on http://192.168.0.124
✓ Web: http://192.168.0.124
  Login: yourLogin / yourPassword
Starting with mode ON1

[MEMORY] Periodic check - Free: 400768 bytes (6 logs)
```
✅ **Key indicators of success:**  
✓ Time synced (UTC+..)  
✓ Web: http://192.168.0.124 (IP adress in the example)  
✓ Onboard green LED on Pico 2W is lit 🟩

### F3. Note Your Pico's IP Address
- **01.** Look for the line: `[WEB] http://192.168.0.xxx:80`
- **02.** **Write down this IP address** – you'll need it to access the web interface.

### F4. Test Physical Buttons
- **01.** Press **Button 1** (short press): LEDs should cycle through modes: FULL → CHASE → OFF
- **02.** Observe console output:
```
[MODE] Mode: ON -> CHASE
[CHASE] Starting animation to LED 9
[CHASE] Animation complete, LED 9 active
[MODE] Mode: CHASE -> OFF
[MODE] Mode: OFF -> ON
... 
```
- **03.** Press **Button 1** (long press ~3 seconds): Script should stop with message: "Script stopped by user"
```
Button 1 long press - shutting down...
GPIO cleaned

==========================================
FINAL STATISTICS
Started: 31/12/2025 - 09:39:16
Total ON time: xxm
==========================================
Program terminated
```
- **04.** Press **Button 2** (long press ~3 seconds): Pico should reboot (console will show restart sequence)
```
Button 2 long press - restarting...
[SYSTEM] Manual restart initiated

==================================================
RESTARTING...
==================================================
```
**Note:** The Thonny console correctly displays the "restartig sequence" but then loses the connection: this is normal operation.  
The device remains controllable with its buttons or via the web interface, but no longer via Thonny.

✅ **If buttons respond correctly, hardware is functioning properly.**
### 🎉 CONGRATULATIONS 🎉 Your ML01 device is now configured and ready to run independently.
---

## G. STANDALONE OPERATION
### G1. Disconnect from Computer
- **01.** In Thonny, click the **red "Stop" button** (■) to halt the running script.
- **02.** Close Thonny.
- **03.** **Disconnect** the Pico from your computer.

### G2. Connect to Power Supply
- **01.** Connect the **5.1V 2.5A micro-USB power supply** to the Pico.
- **02.** The **`main.py`** script will **automatically start** on boot.
- **03.** Wait 5-10 seconds for:  
        ✓ Wi-Fi connection to establish<br>
        ✓ Synchronization with the NTP server<br>
        ✓ Web server to start<br>
        ✓ LEDs to activate in default mode<br>

### G3. Confirm Auto-Start
- **01.** Check that **LEDs illuminate** (FULL mode by default).
- **02.** Check that **Pico onboard LED** is lit.

### G4. To access the web interface and control your ML01 remotely
See 📖 [USAGE](../01_docs/ML01-usage.md) to know how to use ML01 for daily operation and monitoring, this document covers:  
- LED OPERATING MODES
- PHYSICAL BUTTON CONTROLS
- ONBOARD LED INDICATOR (Pico LED)
- WEB INTERFACE ACCESS
- WEB INTERFACE FEATURES
- SYSTEM STATISTICS
---

## H. TROUBLESHOOTING
### H1. Thonny doesn't detect Pico
✓ Ensure micro-USB cable supports **data transfer** (not just charging).  
✓ Try a different USB port on your computer.  
✓ Restart Thonny and reconnect Pico.  
✓ Re-flash MicroPython firmware.

### H2. "WiFi connection failed" error
✓ Verify SSID and password are correct (case-sensitive).  
✓ Ensure Wi-Fi network is **2.4 GHz** (not 5 GHz).  
✓ Move Pico closer to Wi-Fi router.  
✓ Check if network has MAC address filtering (whitelist Pico's MAC).  
✓ Restart your router.

### H3. No IP address displayed
✓ Ensure Wi-Fi credentials are correct.  
✓ Check that router DHCP is enabled.  
✓ Try connecting Pico to a different Wi-Fi network for testing.

### H4. LEDs don't light up
✓ Verify power supply provides 5.1V and sufficient current (2.5A).  
✓ Check solder joints on LED connections (see assembly guide).  
✓ Test with multimeter: measure voltage across LED anode (+5V) and cathode.  
✓ Verify TPIC6B595N orientation and wiring.

### H5. Buttons don't respond
✓ Check button solder joints.  
✓ Verify buttons are connected to correct GPIO pins (GPIO 4 and GPIO 5).  
✓ Test button continuity with multimeter.

### H6. "ModuleNotFoundError: microdot" error
✓ Ensure `microdot.py` is uploaded to Pico root directory.  
✓ Verify filename is exactly `microdot.py` (case-sensitive).  
✓ Re-upload `microdot.py` following corresponding section.

### H7. Script doesn't auto-start on power-up
✓ Ensure file is named exactly `main.py` on the Pico.  
✓ Check that `main.py` is in the **root directory** of Pico (not in a subfolder).  
✓ Verify no syntax errors in `main.py` (test run in Thonny first).

###
---

*Revision date: 2026.01.26*<br>
© RELEASE255 | All rights reserved

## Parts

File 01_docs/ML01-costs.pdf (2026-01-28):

# PROJECT COST ESTIMATE

PROJECT | ML01
VERSION | ML01v01RevB
DATE | 28.01.2026
ID | COMPONENTS | MANUFACTURER | MANUFACTURER ID | SUPPLIER | SUPPLIER ID | QTY | UNIT PRICE * | SET PRICE
01 | RASPBERRY PICO 2W RP2350 THT | RASPBERRY | SC1634 | Adafruit BerryBase Electronics Conrad Electronic Digikey Farnell Kiwi electronics LCSC Electronics Mouser Electronics Pimoroni Reichelt elektronik Sparkfun Electronics The PiHut TME Electronic Components ... | | 1 | 7.70 | 7.70
02 | TPIC6B595N – POWER SHIFT REGISTER | TI | TPIC6B595N | | | 2 | 1.56 | 3.12
03 | LED 5MM YELLOW 2500 MCD 60DEG | HUIYUAN | 5034Y1D-ESB-E | | | 16 | 0.20 | 3.20
04 | METAL FILM RESISTOR 160Ω THT 1% 0.6W | YAGEO | MF0207FTE52-160R | | | 16 | 0.02 | 0.29
05 | CERAMIC CAPACITOR X7R 100nF THT 10% | MURATA | RDER71H104K0S1H03A | | | 7 | 0.09 | 0.63
06 | ELECTRO RADIAL CAPACITOR 100µF Ø06.30 H11.20 | PANASONIC | EEUFR1E101B | | | 1 | 0.15 | 0.15
07 | RESETTABLE FUSE PTC 750 mW - 770 mOhm | BOURNS | MF-R050 | | | 1 | 0.26 | 0.26
08 | PUSH BUTTON 6x6 H5 1.6N BROWN | DIPTRONICS | DTS-62N | | | 2 | 0.34 | 0.68
09 | POWER SUPPLY 12.5W 5.1V 2.5A MICRO USB | RASPBERRY | KSA-13B-051250-HE/EU | | | 1 | 7.90 | 7.90
10 | PCB ML01v01_THT_RevB | RELEASE255 | ML01v01RevB-pcb | PCBWAY | W904950AS3FR3 | 1 | 18.00 | 18.00
11 | STAND FOR PCB | RELEASE255 | ML01-pcbstand-v01 | price depends on the material and slicer settings | | 1 | 5.00 | 5.00
COMPONENTS SUBTOTAL | 46.93
SHIPPING | 15.00
TOTAL in CHF | 61.93
* Indicative prices as of 11.01.2026

# D R A F T

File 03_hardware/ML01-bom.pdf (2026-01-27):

# BILL OF MATERIALS

PROJECT | ML01
VERSION | ML01v01RevB
DATE | 27.01.2026
ID | COMPONENTS | QTY | SCHEMATIC ITEM | FOOTPRINT | MANUFACTURER | MANUFACTURER ID
01 | RASPBERRY PICO 2W RP2350 THT | 1 | RP2350 | Module_RaspberryPi_Pico:RaspberryPi_Pico_Common_THT | RASPBERRY | SC1634
02 | TPIC6B595N – POWER SHIFT REGISTER | 2 | U1, U2 | Package_DIP:DIP-20_W7.62mm | TEXAS INSTRUMENTS | TPIC6B595N
03 | LED 5MM YELLOW 2500 MCD 60DEG | 16 | D1 to D16 | LED_THT:LED_D5.0mm_Clear | HUIYUAN | 5034Y1D-ESB-E
04 | METAL FILM RESISTOR 160Ω THT 1% 0.6W | 16 | R1 to R16 | Resistor_THT:R_Axial_DIN0207_L6.3mm_D2.5mm_P10.16mm_Horizontal | YAGEO | MF0207FTE52-160R
05 | CERAMIC CAPACITOR X7R 100nF THT 10% | 7 | C1 to C7 | Capacitor_THT:C_Disc_D5.0mm_W2.5mm_P2.50mm | MURATA | RDER71H104K0S1H03A
06 | ELECTRO RADIAL CAPACITOR 100µF Ø06.30 H11.20 | 1 | C8 | Capacitor_THT:C_Radial_D6.3mm_H11.0mm_P2.50mm | PANASONIC | EEUFR1E101B
07 | RESETTABLE FUSE PTC 750 mW - 770 mOhm | 1 | F1 | Fuse_Bourns_MF-R050:Fuse_Bourns_MF-R050 | BOURNS | MF-R050
08 | PUSH BUTTON 6x6 H5 1.6N BROWN | 2 | SW1, SW2 | Button_Switch_THT:SW_PUSH_6mm_H5mm | DIPTRONICS | DTS-62N
09 | POWER SUPPLY 12.5W 5.1V 2.5A MICRO USB | 1 | - | - | RASPBERRY | KSA-13B-051250-HE/EU
10 | PCB ML01 THT | 1 | - | - | RELEASE255 | ML01v01RevB-pcb
11 | STAND FOR PCB (to be printed according to 3D file) | 1 | - | - | RELEASE255 | ML01-pcbstand-v01

SPDX-License-Identifier: CC-BY-SA-4.0
Creative Commons Attribution-ShareAlike 4.0 International License Copyright (c) RELEASE255

YOU ARE FREE TO:
- Share, copy and redistribute the material in any medium or format.
- Adapt, remix, transform, and build upon the material.

UNDER THE FOLLOWING TERMS:
- Attribution - You must give appropriate credit, provide a link to the license, and indicate if changes were made. You may do so in any reasonable manner, but not in any way that suggests the licensor endorses you or your use.
- ShareAlike - If you remix, transform, or build upon the material, you must distribute your contributions under the same license as the original.
- No additional restrictions - You may not apply legal terms or technological measures that legally restrict others from doing anything the license permits.

NOTICES:
- You do not have to comply with the license for elements of the material in the public domain or where your use is permitted by an applicable exception or limitation.
- No warranties are given. The license may not give you all of the permissions necessary for your intended use. For example, other rights such as publicity, privacy, or moral rights may limit how you use the material.

To view a copy of this license, visit: http://creativecommons.org/licenses/by-nc-sa/4.0/

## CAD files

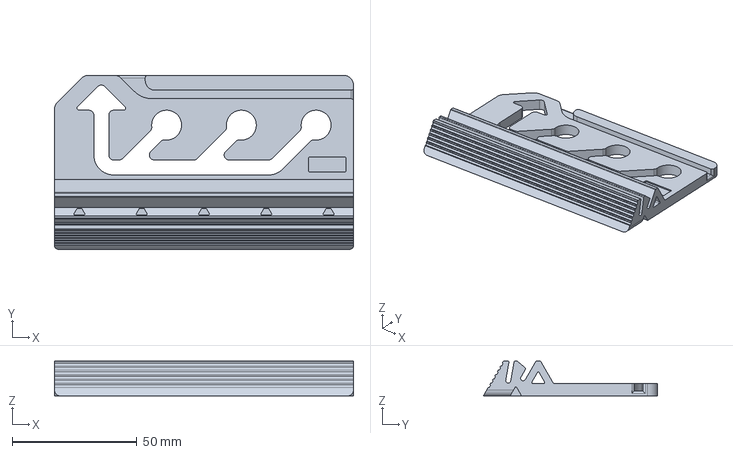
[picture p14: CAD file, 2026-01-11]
04_3dmodels/ML01-pcbstand-v01.stp
120.0 x 70.0 x 14.0 mm

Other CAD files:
04_3dmodels/ML01-pcbstand-v01.stl

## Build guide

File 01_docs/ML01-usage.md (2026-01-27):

# ML01 PROJECT – USAGE GUIDE
This guide explains how to use your ML01 device for daily operation and monitoring.

**Key Features:**
- 16 controlled yellow LEDs
- 3 operating modes (OFF, FULL, CHASE)
- 2 physical button controls for local operation
- Web interface for remote control and monitoring
- Automatic NTP time synchronization
---

## A. LED OPERATING MODES
The ML01 is an LED controller featuring three operating modes, physical button controls, and a web-based remote interface.  
Once configured, the device operates autonomously with automatic Wi-Fi reconnection and time synchronization.
### A1. OFF Mode
- **Description:** All 16 LEDs are turned off.
- **Use case:** Power saving, nighttime operation, or when lighting is not needed.
- **Power consumption:** ~0.18 Wh (Pico only)

<p align="center">
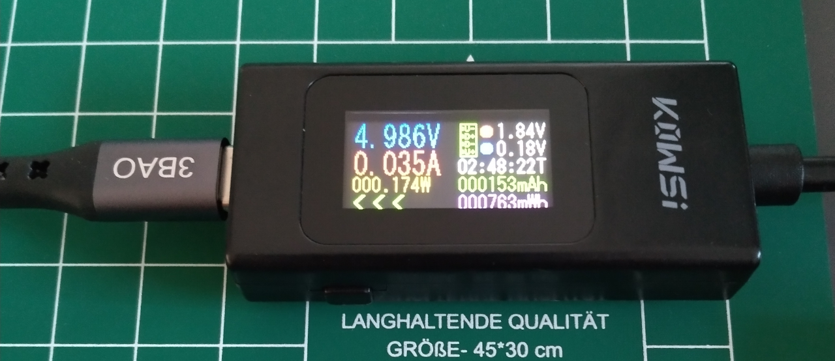
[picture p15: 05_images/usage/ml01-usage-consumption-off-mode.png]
  
</p>

### A2. FULL Mode
- **Description:** All 16 LEDs are continuously illuminated at full brightness.
- **Default behavior:** This is the default mode when the device starts.
- **Use case:** Maximum visibility, status indication, or testing all LEDs.
- **Power consumption:** ~1.25 Wh

<p align="center">
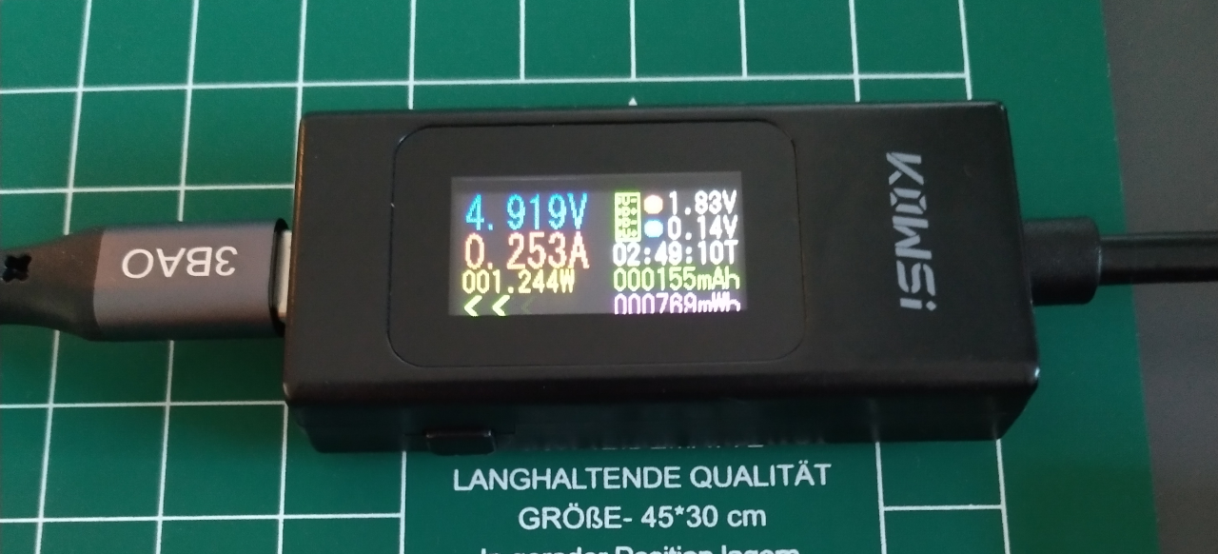
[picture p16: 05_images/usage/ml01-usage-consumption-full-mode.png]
  
</p>

### A3. CHASE Mode
- **Description:** Visual indication of the time with only 1 LED lit at a time, and special hourly animation with all LEDs.
- **Regular minute display:**  
        ✓  Each LED illuminates for 3.75 minutes (225 seconds)<br>
        ✓  LED position synchronized with real-time clock (NTP)<br>
        ✓  Completes full cycle every 60 minutes (16 LEDs × 3.75 min = 60 min)<br>
- **Special Hourly animation (each HH:00:00) :**  
        ✓ All LEDs light up sequentially (LED 1 → 16), three times in a row<br>
        ✓ All LEDs flash simultaneously 3 times at 1-second intervals<br>
        ✓ Chase mode resumes with only LED 1 active<br>
- **Use case:** Visual time indicator, demonstration of sequential control, and fun!
- **Power consumption:** ~0.25 Wh

<p align="center">
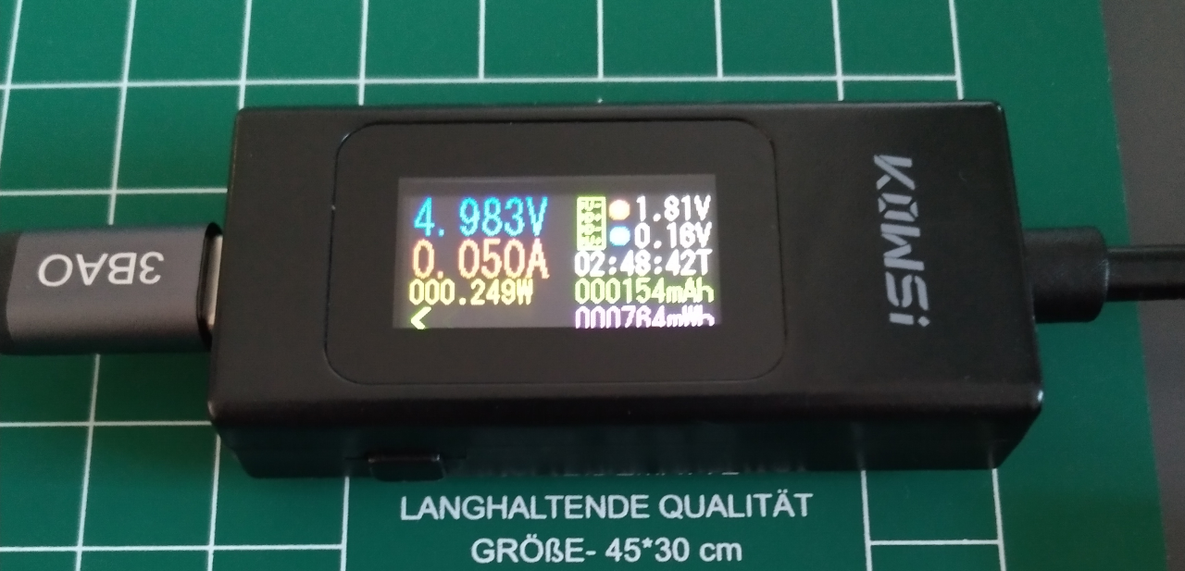
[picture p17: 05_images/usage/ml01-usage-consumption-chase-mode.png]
  
</p>

---

## B. PHYSICAL BUTTON CONTROLS
The ML01 features 2 push buttons for local control without requiring network access.
### B1. Button 1 Functions
**Short Press (< 1.5 seconds):**
- Cycles through modes in sequence: FULL → CHASE → OFF → FULL → ...
- Each press advances to the next mode
- Mode change is logged in system logs

**Long Press (≥ 1.5 seconds):**
- Stops script execution and shuts down gracefully
- Turns off all LEDs
- Clears GPIO pins
- Displays final statistics in Thonny shell if connected

### B2. Button 2 Functions
**Short Press (< 1.5 seconds):**
- Currently not assigned (reserved for future functionality)

**Long Press (≥ 1.5 seconds):**
- Performs a full system restart
- Clears all logs stored in RAM
- Useful for occasionally recovering from errors
---

## C. ONBOARD LED INDICATOR (Pico LED)
The Raspberry Pi Pico 2W has a small onboard LED that provides status information:

| LED Behavior | Meaning |
|---|---|
| **Solid ON** | Wi-Fi connected and operational |
| **OFF** | Wi-Fi disconnected or not configured |
| **Fast blinking** (5 Hz) | New remote connection detected (for 10 seconds) |
---

## D. NETWORK FEATURES
### D1. Local Wi-Fi Connection
- Connects to **2.4 GHz Wi-Fi** networks only (5 GHz not supported)
- Configured via `main.py` during setup (see Settings Guide)
- Uses DHCP to obtain IP address automatically

### D2. Automatic Reconnection
- Checks Wi-Fi connection every **10 minutes**
- Attempts **2 reconnection cycles** if connection is lost
- Waits **20 seconds** between reconnection attempts
- Logs all connection events for troubleshooting

### D3. NTP Time Synchronization
- Synchronizes with NTP server on boot and after Wi-Fi reconnection
- Timezone offset configured in `main.py`
- Required for accurate CHASE mode timing and log timestamps
- Requires active internet connection (not just local Wi-Fi)
---

## E. WEB INTERFACE ACCESS
Finding Your Pico's IP Address with 2 methods:  
<br>
**Method 1: Thonny Shell during setup**  
When running the script in Thonny, the IP address is displayed in the shell output like in the example below:
```
[WEB] http://192.168.0.124:80
[SYSTEM] Web server on http://192.168.0.124
✓ Web: http://192.168.0.124
```
**Method 2: Router Admin Panel**
- Access your router's configuration page (usually `192.168.1.1` or `192.168.0.1`)
- Look for "Connected Devices" or "DHCP Client List"
- Find your device

### E1. Connecting to Web Interface
- **01.** Open a web browser on any device connected to the **same Wi-Fi network** as the Pico.
- **02.** Enter the Pico's IP address in the browser address bar, example: http://192.168.0.124  
**Note:** The web server runs on **port 80** (standard HTTP), so no port number is needed in the URL.
- **03.** If authentication is enabled (default), you will see a login prompt.
- **04.** Enter the credentials configured in `main.py`
- **05.** Click **"Log In"** or press Enter.

### E2. Screenshots and Interface Preview
**Authentication:**
<p align="center">
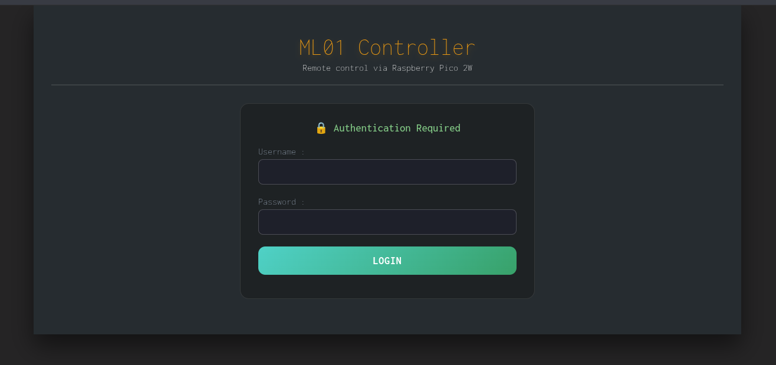
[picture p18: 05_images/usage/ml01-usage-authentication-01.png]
  
</p>

**Main Control Panel & System Statistics:**
<p align="center">
  
</p>

**Log Viewer:**
<p align="center">
  
</p>

---

## F. WEB INTERFACE FEATURES
### F1. Remote Control Buttons
The web interface provides four main control buttons:
- Press the **ON** button for FULL mode
- Press the **CHASE** button for time-synchronized display
- Press the **OFF** button to turns off all 16 LEDs immediately
- Press the **RESTART** button to reboots the Raspberry Pi Pico

### F2. System Information Display
The web interface shows also real-time system status:
#### **Network Information**
- **SSID:** Name of the Wi-Fi network the Pico is connected to
- **IP:** Current IP address of the Pico
#### **Operational Status**
- **START:** Date and time when the script started in `DD/MM/YYYY - HH:MM:SS` format
- **UPTIME:** Total time since device boot in `HH MM` format (time spent in FULL mode in parentheses)
#### **Temperature Monitoring**
- **PICO TEMP:** Internal temperature of the RP2350 microcontroller in °C
- **STATUS:** Temperature classification according to the table below

| Temperature Range | Status | Description |
|---|---|---|
| < 50°C | **Normal** | Optimal operating temperature |
| 50°C – 60°C | **Warm** | Slightly elevated, still safe |
| 60°C – 70°C | **High** | Monitor closely, ensure ventilation |
| > 70°C | **Critical** | Unlikely under normal operation |

**Notes:**
- Temperature readings are approximate and for monitoring purposes only
- The RP2350 has a maximum operating temperature of 85°C, but sustained operation above 70°C is not recommended
- No automatic action is taken if temperature exceeds thresholds (temperature warnings are informational only)

### F3. System Logs
The web interface includes a comprehensive logging system for monitoring and troubleshooting.
#### **Log Display Features**
- **Pagination:** Displays 100 log entries per page (up to 10 pages)
- **Newest first:** Most recent logs appear at the top of page 1
- **Total capacity:** Stores up to **1,000 log entries** in RAM
- **Auto-rotation:** When limit is reached, oldest entries are automatically deleted

#### **Log Categories**
Logs can be filtered by category:

| Category | Description |
|---|---|
| **ALL** | Shows all log entries |
| **MODE** | LED mode changes |
| **WIFI** | Wi-Fi connection events |
| **SECURITY** | Access control and authentication |
| **SYSTEM** | System operations & Time sync |
| **ERROR** | Errors, connection or NTP sync failed |

#### **Log Entry Format**
Each log entry contains:
- **Timestamp:** Date and time in `DD/MM/YYYY - HH:MM:SS` format
- **Type:** Category label (MODE, WIFI, SECURITY, SYSTEM, ERROR)
- **Message:** Detailed description of the event

#### **Export Logs to CSV with EXPORT Button**
- Downloads all current logs as a CSV file
- Filename in `ML01_logs_page1_YYYY-MM-DD.csv` format

#### **Clear Logs with CLEAR Button**
- Deletes all log entries from RAM
- Frees up memory (could be useful if you are approaching the entry limits)
---

## G. SYSTEM STATISTICS (Thonny Shell Only or similar IDE software)
When stopping the script using **Button 1 long press**, the device displays final statistics in the Thonny shell if connected.  
Note that these statistics are not shown in the web interface:
```
Button 1 long press - shutting down...
GPIO cleaned

==========================================
FINAL STATISTICS
Started: 31/12/2025 - 09:39:16
Total ON time: xxm
==========================================
Program terminated
```
---

## H. IMPORTANT NOTES
### H1. Reminder Of The Safety and Usage Rules Detailed in 📖 [SPECIFICATIONS](../01_docs/ML01-specifications.md)
⚠️ **LIMITATIONS AND WARNINGS** ⚠️
- **Indoor use only**
- **Always use the recommended power supply**
- **Not CE/FCC certified** | Hobbyist/educational use only
- **DIY assembly required** | Soldering skills necessary
- **Open PCB design** | Avoid contact with conductive materials
- **ESD sensitive** | Handle with antistatic precautions
- **No over-voltage protection** beyond PTC fuse
- **Wi-Fi stability** depends on local environment and interference

### H2. Data Persistence
- Logs are NOT persistent
- All logs are stored in RAM only
- Logs are completely erased when the Pico reboots
- Export logs to CSV before restarting if you need to keep them
- Statistics are NOT persistent
- Uptime and ON-time counters reset to zero on reboot
- If you need historical data, note statistics before restarting

### H3. Log Rotation
- Maximum 1000 log entries stored in RAM
- When limit is reached, oldest entries are automatically deleted
- New logs continue to be added (FIFO: First In, First Out)
- Export logs periodically if you need long-term records

### H4. Security Considerations
- If `AUTH_ENABLED = True` in `main.py`, all web access requires username/password
- Credentials are transmitted using HTTP Basic Authentication
- Not encrypted – suitable for local networks only, do not expose to public internet
- If `IP_WHITELIST_ENABLED = True` and `ALLOWED_IPS` is populated, only specified IP addresses can access the web interface
- Empty `ALLOWED_IPS` list with authentication enabled = **no one can connect**
- Update `ALLOWED_IPS` if your device IP changes (DHCP)
---

## I. TROUBLESHOOTING COMMON ISSUES
### I1: Web interface not loading
- **01.** Verify Pico is connected to Wi-Fi (check onboard LED – should be solid ON)
- **02.** Confirm you're on the **same Wi-Fi network** as the Pico
- **03.** Verify IP address is correct (check Thonny shell or router)
- **04.** Check if your IP is in `ALLOWED_IPS` list (if IP filtering enabled)
- **05.** Try accessing from a different device to rule out browser/firewall issues
- **06.** Restart the Pico

### I2: "Authentication required" prompt keeps appearing
- **01.** Verify you're entering the correct username and password from `main.py`
- **02.** Check for **extra spaces** in credentials (copy-paste carefully)
- **03.** Try a different browser (cached credentials may be incorrect)
- **04.** If you forgot the password, you must:  
        - Edit `main.py` in Thonny<br>
        - Change `AUTH_USERNAME` and/or `AUTH_PASSWORD`<br>
        - Re-upload `main.py` to the Pico<br>
        - Restart the Pico<br>

### I3: "Access denied" error
Your IP address is not in the `ALLOWED_IPS` whitelist:
- **01.** Find your device's current IP address
- **02.** Edit `main.py`
- **03.** Add your IP to the `ALLOWED_IPS` list
- **04.** Re-upload `main.py` to the Pico
- **05.** Restart the Pico

### I4: CHASE mode LED position incorrect
- **01.** Check logs for "Time synced" message
- **02.** Ensure internet connection is available (not just local Wi-Fi)
- **03.** Restart Pico to force NTP sync
---

## J. RELATED DOCUMENTATION
- see 📖 [SPECIFICATIONS](../01_docs/ML01-specifications.md)
- see 📖 [ASSEMBLY GUIDE](../01_docs/ML01-assembly.md)
- see 📖 [SETTINGS GUIDE](../01_docs/ML01-settings.md)

**For technical support or questions, please open an issue on the GitHub repository.**
###
---

*Revision date: 2026.01.27*<br>
© RELEASE255 | All rights reserved

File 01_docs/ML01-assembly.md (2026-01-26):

# ML01 PROJECT – ASSEMBLY GUIDE
**Recommended time: ~5 hours** depending on experience and available materials.

## A. REQUIRED MATERIALS
### A1. Soldering Equipment
- Soldering iron with temperature control (power of approximately 65W)
- Chisel soldering tip with 1.20 or 1.60 mm diameter
- Solder wire Sn99.3Cu0.7 (lead-free) 0.70 mm diameter
- Metal wool spiral for cleaning the soldering iron tip
- Damp sponge for additional tip cleaning
- Desoldering pump or desoldering wick (for corrections)
- Soldering mat (heat-resistant, ESD-safe recommended)

### A2. Tools
- Fine wire cutting pliers (flush cutters)
- Needle-nose pliers (for component placement and bending)
- PCB holder/stand for easier handling
- Foam pads to stabilize the PCB during soldering

### A3. Testing Equipment
- Digital multimeter (for continuity and short-circuit testing)
- Magnifying glass (for solder joint inspection)

### A4. Cleaning and Safety
- Good task lighting
- Fume extractor or well-ventilated workspace
- Flux remover spray with brush
- ESD thin protective gloves
- Safety glasses (protection from flying component leads and flux remover spray)

### A5. Check that you have all the components listed in the BOM
- Refer to the [BOM](../03_hardware/ML01-bom.pdf).
- Note: the stand for PCB must be printed according to the provided 3D file.
---

## B. PREPARATION
### B1. Safety precautions ⚠️
- **Ventilation:** Work in a well-ventilated area or use a fume extractor. Do not inhale soldering fumes.
- **Temperature:** Soldering iron reaches 360°C – handle with care and use a proper stand.
- **Eye Protection:** Wear safety glasses when cutting component leads to prevent injury.
- **Flux Remover:** Follow manufacturer's instructions carefully. Use in ventilated area and avoid skin/eye contact.
- **ESD Protection:** Handle the components with antistatic precautions.

### B2. Resistors (16×)
**Difficulty level: easy**
- **01.** Bend the resistor leads at a 90° angle to match PCB pad spacing.
- **02.** Pre-form all 16 resistors to ensure consistent placement and centering on the PCB.
- **03.** Pre-cut leads so they protrude approximately 6 mm from the PCB to maximize access.

<p align="center">
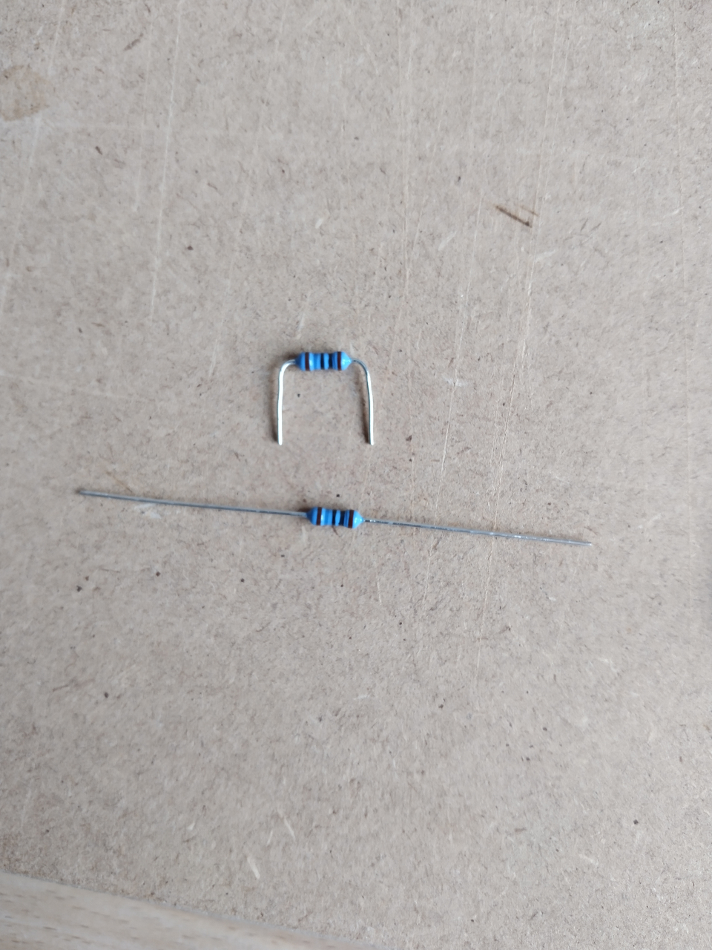
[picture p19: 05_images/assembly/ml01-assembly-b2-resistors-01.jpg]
  
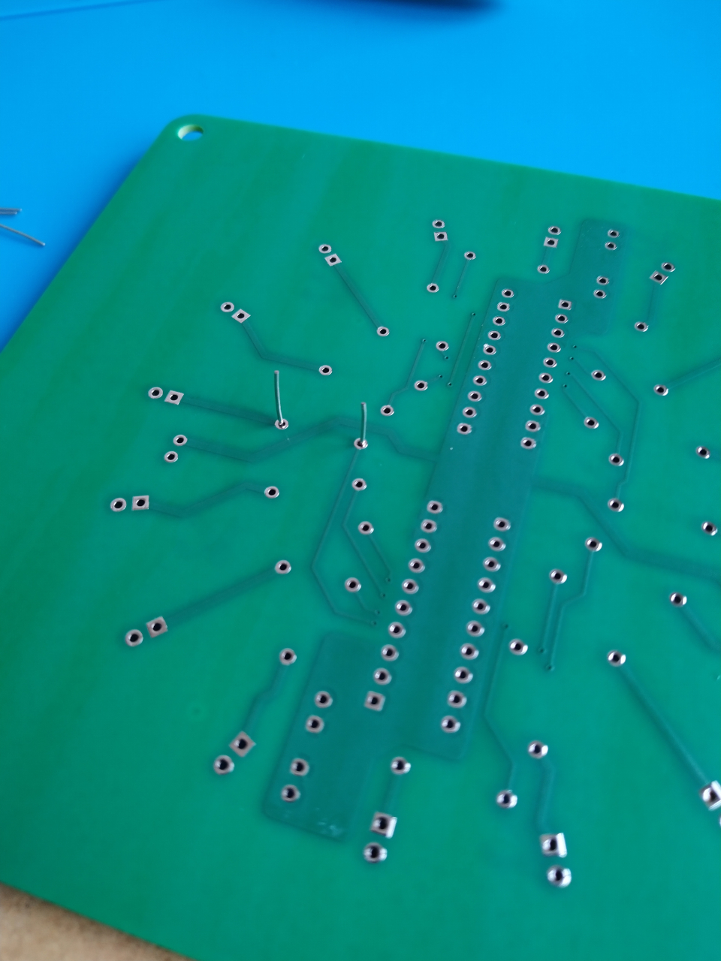
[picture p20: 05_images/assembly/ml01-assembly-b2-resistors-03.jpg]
  
</p>

### B3. TPIC6B595N Shift Registers (2×)
**Difficulty level: easy**  
Slightly bend all IC pins **inward** to facilitate insertion into PCB holes.

<p align="center">
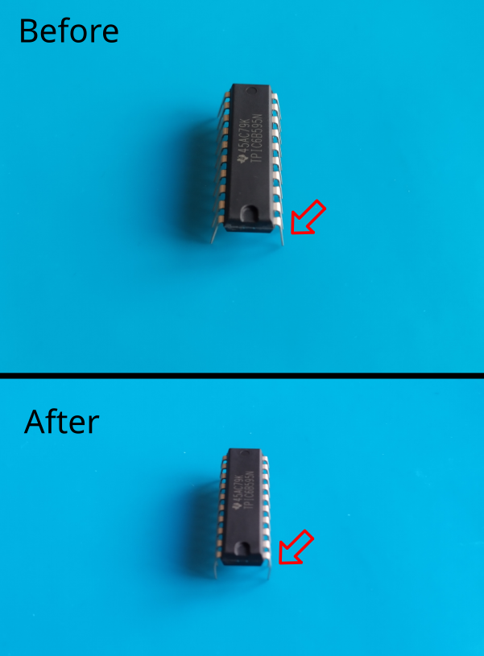
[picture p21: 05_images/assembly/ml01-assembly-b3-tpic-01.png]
  
</p>

### B4. PTC Resettable Fuse (1x) and Electrolytic Capacitor (1x)
**Difficulty level: medium**  
<br>
ℹ️ If you prefer to keep these 2 components straight, you don't need to bend the leads.
- **01.** Bend the resettable fuse leads at a 90° as shown in the photo, in order to minimize its size after welding.
- **02.** Bend the electrolytic capacitor polarized **(so pay attention to the mounting orientation)** for the same reason as before.

<p align="center">
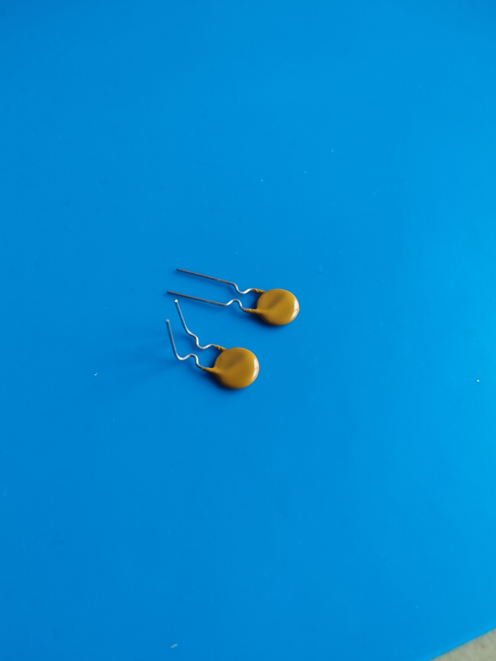
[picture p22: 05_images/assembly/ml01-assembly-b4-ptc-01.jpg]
  
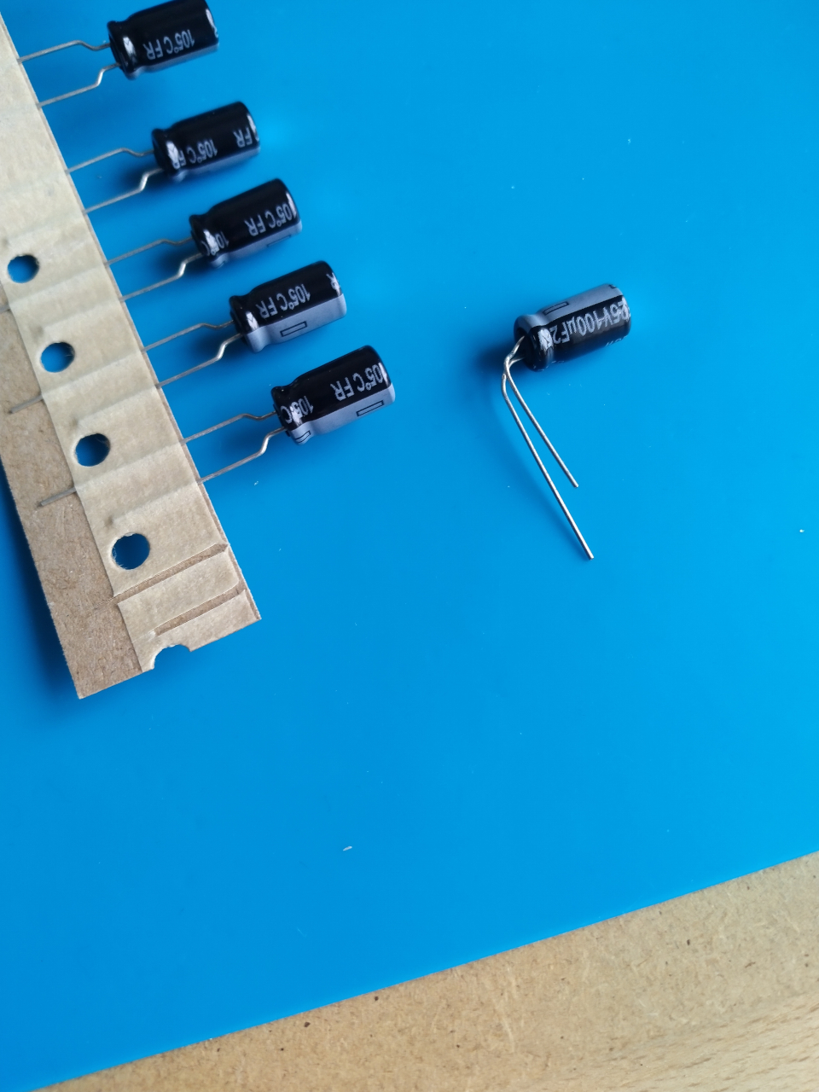
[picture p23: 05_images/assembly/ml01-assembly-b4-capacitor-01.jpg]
  
</p>

### B5. Soldering Temperature Setup
- **01.** Set soldering iron to 360°C (680°F) for lead-free Sn99.3Cu0.7 solder.
- **02.** Allow a few minutes for the iron to reach stable temperature.
- **03.** Clean tip with metal wool & damp sponge before starting.
---

## C. ASSEMBLY (COMPONENT PLACEMENT AND SOLDERING)
**General tips:**
- Solder one lead (or 2 diagonally for the larger components) and check its correct positioning before soldering the other leads.
- Regularly trim soldered component leads to maximize workspace.
- Use the "flip and press" method for components that don't hold themselves: insert components, flip PCB onto mat, and solder.
- Use foam or shims to align the PCB horizontally as best as possible to ensure ideal component placement.
- For the others, use the PCB holder/stand.  

**Summary of the assembly order:**
- **01.** Resistors
- **02.** TPIC6B595N (Power Shift Registers)
- **03.** Ceramic Capacitors
- **04.** Push Buttons
- **05.** Raspberry Pi Pico 2W
- **06.** LEDs
- **07.** PTC (Resettable Fuse)
- **08.** Electrolytic Capacitor

### C1. Resistors (16×)
**Difficulty level: easy**
- **01.** Insert all 16 resistors into their designated positions on the PCB:  
        - Resistors are **non-polarized** (orientation doesn't matter).<br>
        - Ensure resistor bodies sit flat against the PCB surface.
- **02.** Flip the PCB over and place it firmly on the soldering mat.
- **03.** Solder all resistor leads on the underside of the PCB.
- **04.** Trim excess leads with flush cutters, leaving ~2 mm protruding from solder joints.

<p align="center">
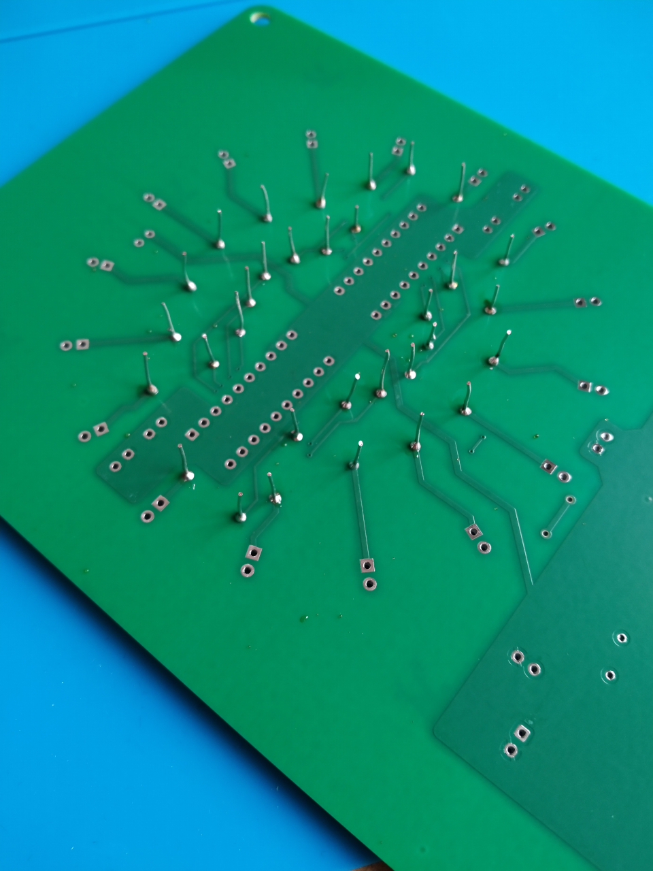
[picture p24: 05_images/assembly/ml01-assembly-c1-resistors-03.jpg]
  
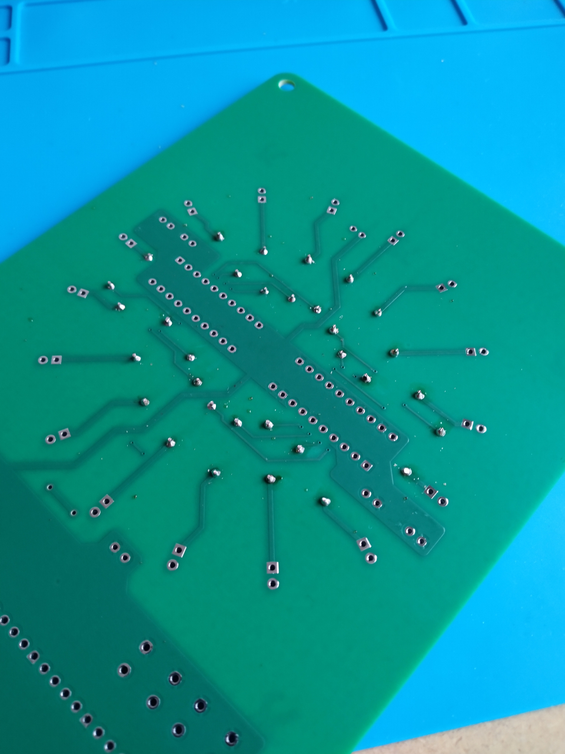
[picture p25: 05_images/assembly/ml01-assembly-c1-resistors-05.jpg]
  
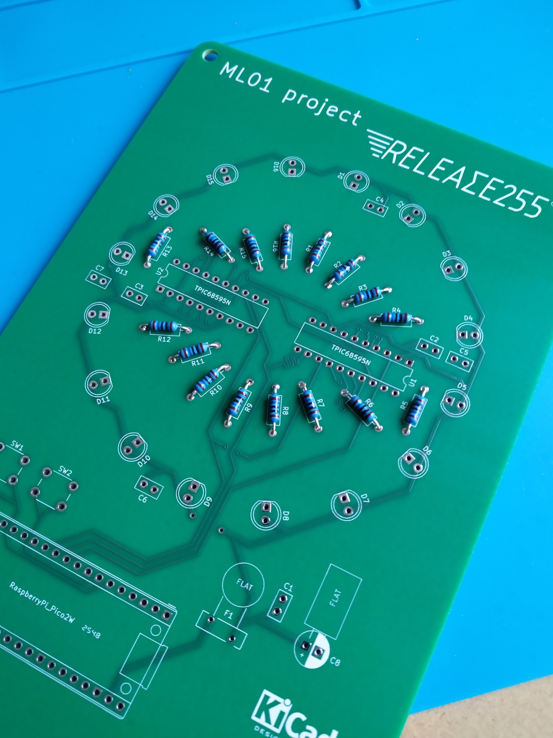
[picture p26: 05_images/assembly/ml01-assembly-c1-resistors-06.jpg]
  
</p>

### C2. TPIC6B595N Power Shift Registers (2×)
**Difficulty level: medium**  
<br>
⚠️ **Correct orientation is essential**
- **01.** Locate the silkscreen markings on the PCB showing IC orientation:  
        - **Pin 1 indicator:** notch or dot on IC package.<br>
        - **Pin 1 position on PCB:** marked with square pad or dot.
- **02.** Insert first TPIC into PCB, aligning Pin 1 with PCB marking:  
        - Ensure **all 20 pins** are correctly inserted into holes.<br>
        - IC body must sit **flat and parallel** to the PCB surface.
- **03.** Flip the PCB over and place it firmly on the soldering mat.
- **04.** Solder **two opposite corner pins first** (e.g., Pin 1 and Pin 20):  
        - This allows repositioning if IC is not flat.<br>
        - Reheat corner pins and press IC down if needed.
- **05.** Once IC is properly seated and straight, solder remaining 18 pins.
- **06.** Repeat steps 01-05 for the second TPIC.
- **07.** It's generally not necessary to cut the legs of TPICs after soldering because they are not very long.

<p align="center">
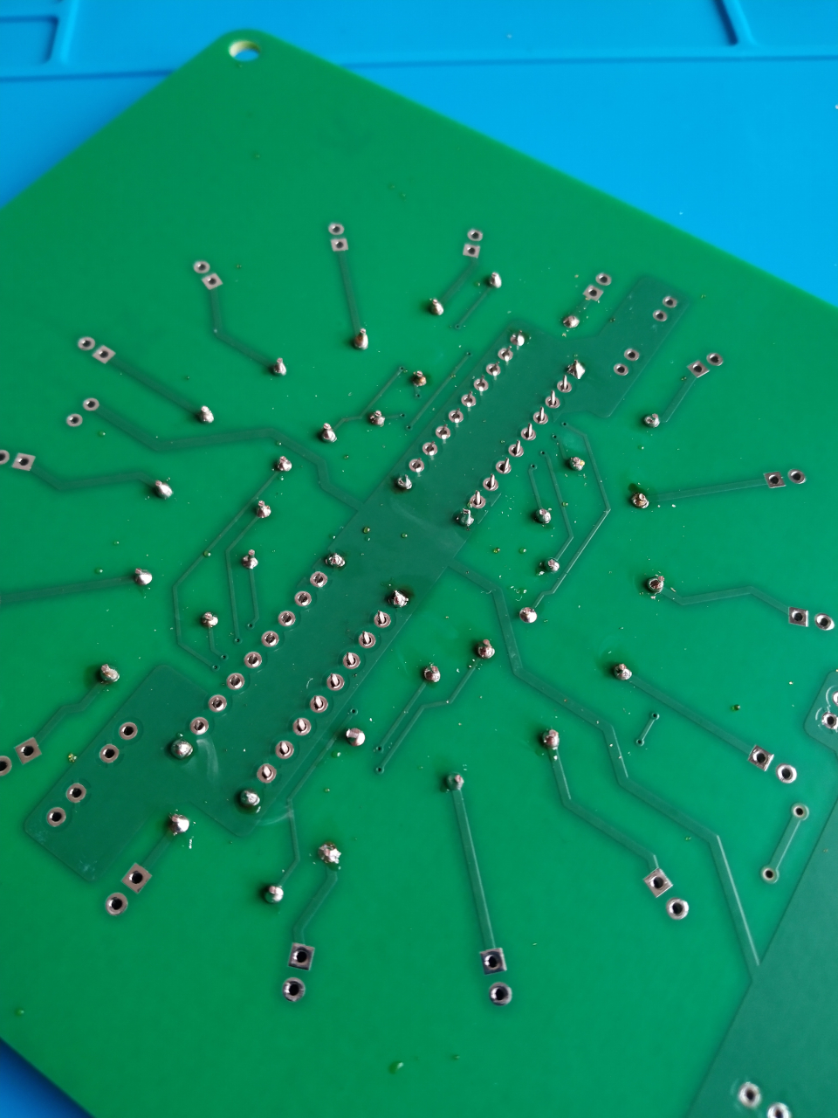
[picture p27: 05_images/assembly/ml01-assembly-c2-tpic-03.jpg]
  
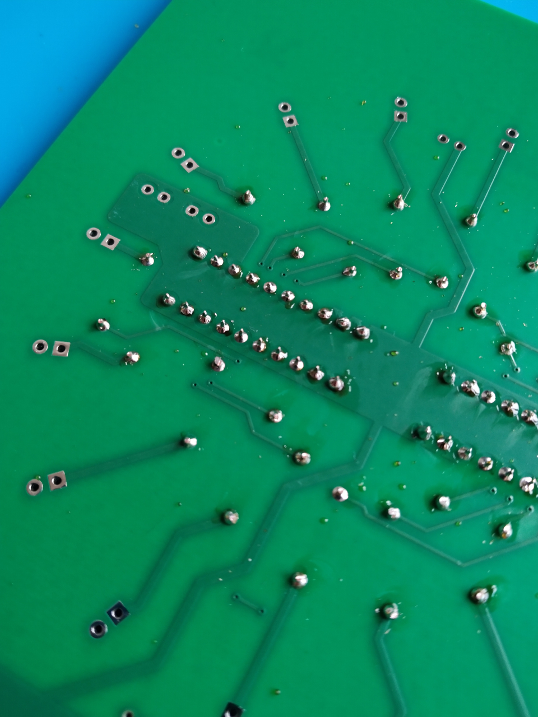
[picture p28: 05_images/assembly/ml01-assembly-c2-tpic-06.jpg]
  
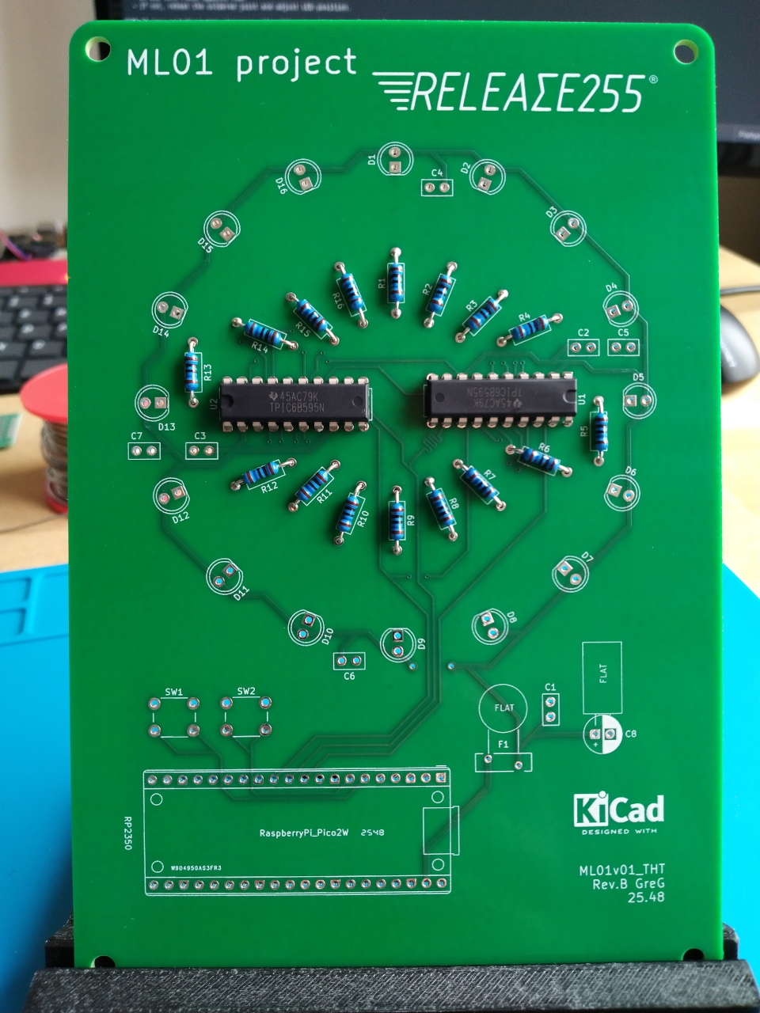
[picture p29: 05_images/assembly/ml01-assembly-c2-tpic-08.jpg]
  
</p>

### C3. Ceramic Capacitors (7×)
**Difficulty level: easy**
- **01.** Insert all 7 ceramic capacitors non-polarized (orientation doesn't matter) into their designated positions.
- **02.** Use PCB stand for easier handling during soldering.
- **03.** Solder all capacitor leads from the underside.
- **04.** Trim excess leads.

<p align="center">
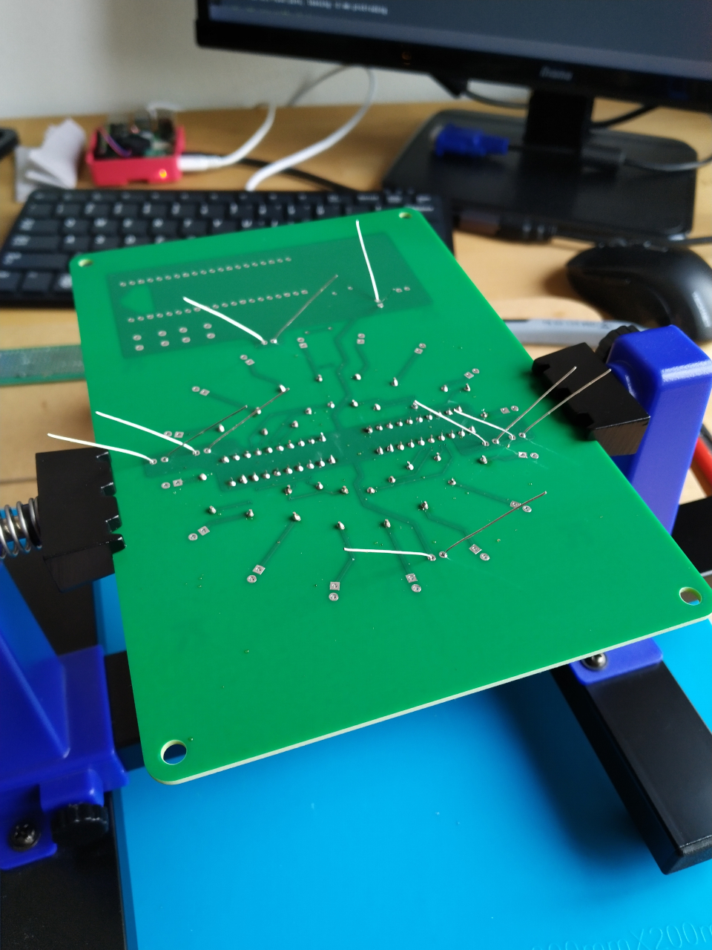
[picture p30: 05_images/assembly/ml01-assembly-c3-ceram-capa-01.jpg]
  
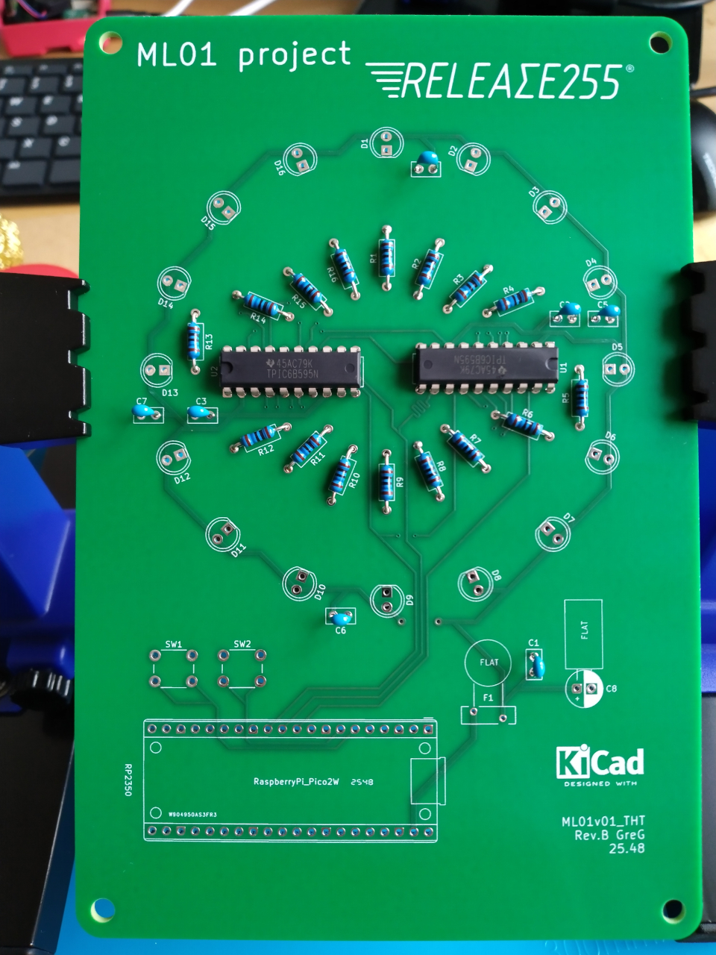
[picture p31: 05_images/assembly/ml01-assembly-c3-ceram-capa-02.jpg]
  
</p>

### C4. Push Buttons (2×)
**Difficulty level: easy**
- **01.** Insert both push buttons into their designated positions:  
        - Buttons are **non-polarized** but have a specific footprint.<br>
        - Ensure buttons are fully seated and perpendicular to PCB.
- **02.** Use PCB stand for easier handling.
- **03.** Solder all 4 pins per button.
- **04.** No lead trimming required (buttons typically sit flush).

<p align="center">
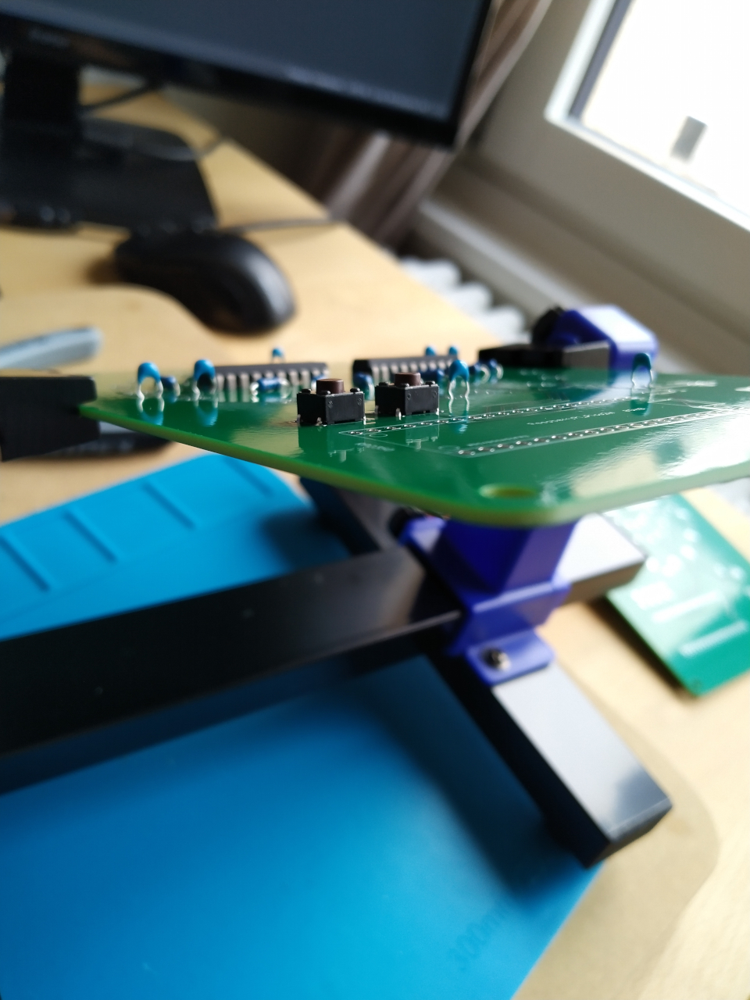
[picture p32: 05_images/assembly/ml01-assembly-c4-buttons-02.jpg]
  
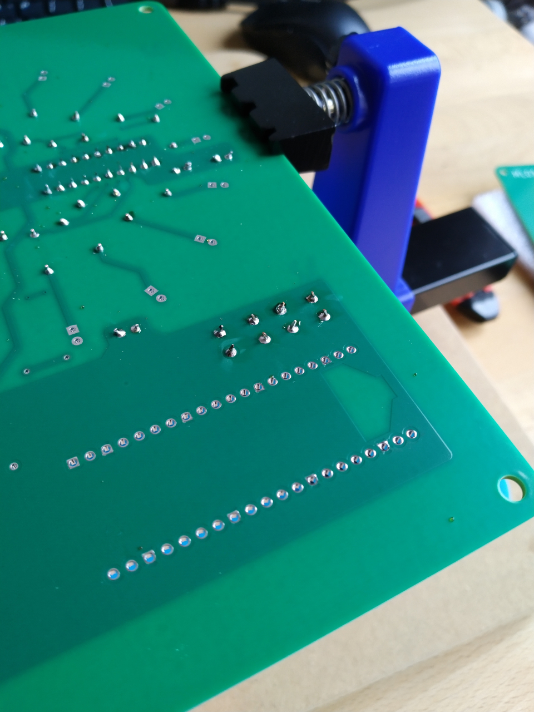
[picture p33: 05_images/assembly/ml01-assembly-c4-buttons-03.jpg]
  
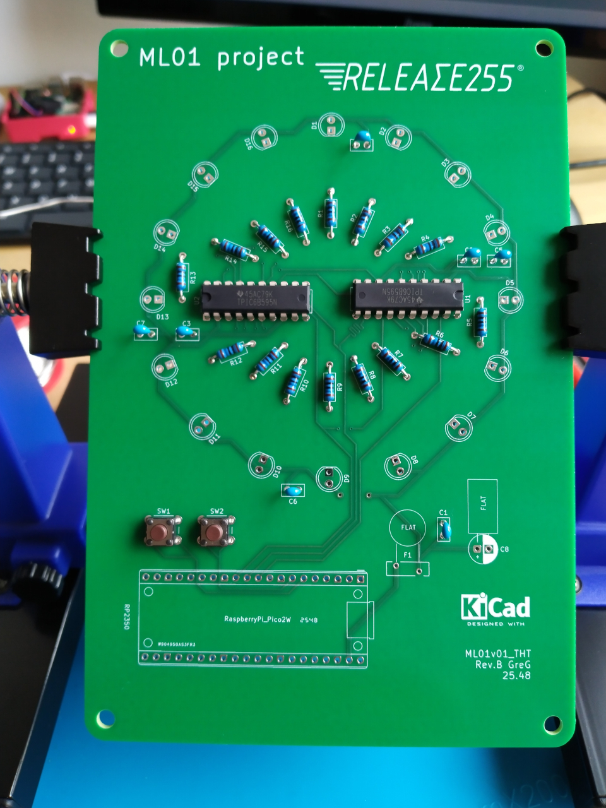
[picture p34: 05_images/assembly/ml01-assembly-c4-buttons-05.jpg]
  
</p>

### C5. Raspberry Pi Pico 2W
**Difficulty level: medium**  
<br>
⚠️ **Correct orientation is essential**
- **01.** Identify correct orientation on PCB silkscreen:  
        - **Micro-USB connector** should align with PCB marking.<br>
        - Ensure **all 40 pins** align with PCB holes.
- **02.** Insert Pico into PCB, then flip assembly the PCB onto mat
- **03.** Check Pico to sit flush against PCB when flipped.
- **04.** Solder **two opposite corner pins first** to secure position.
- **05.** Check that Pico sits flat and parallel to PCB.
- **06.** Solder remaining 38 pins.
- **07.** Trim all Pico pins, leaving ~2 mm protruding.

<p align="center">
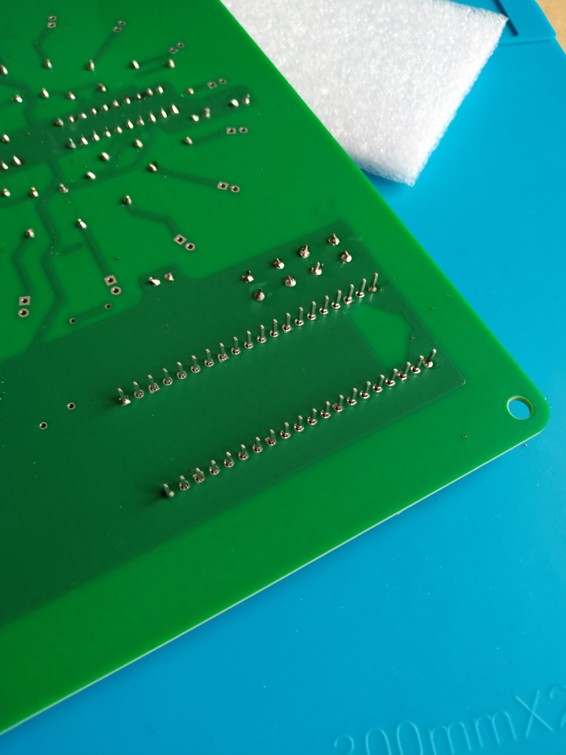
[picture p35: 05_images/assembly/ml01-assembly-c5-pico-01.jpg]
  
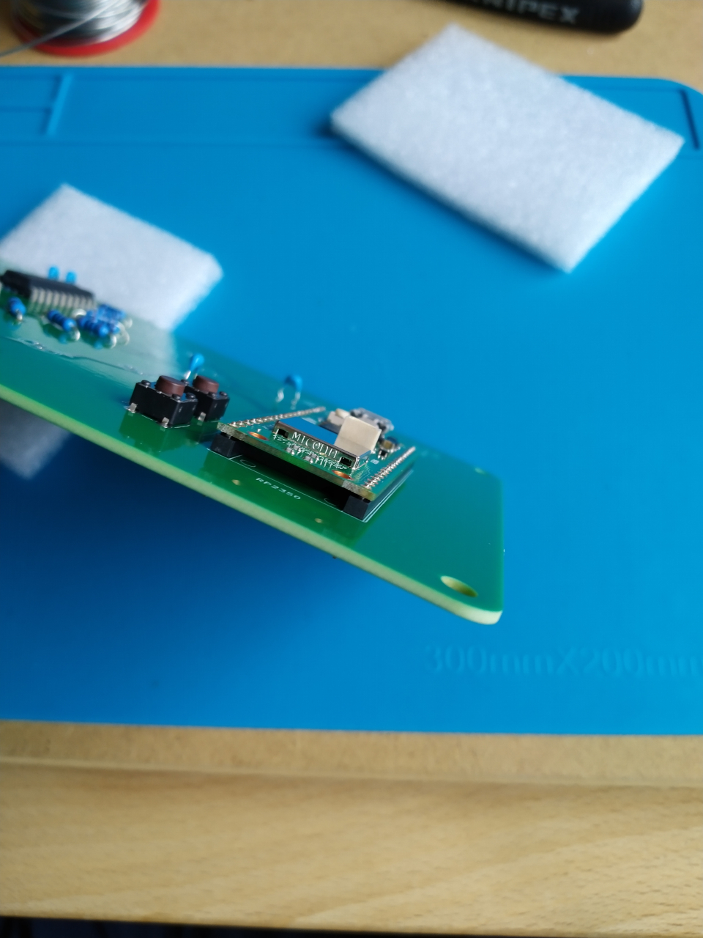
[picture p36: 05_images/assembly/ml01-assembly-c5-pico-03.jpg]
  
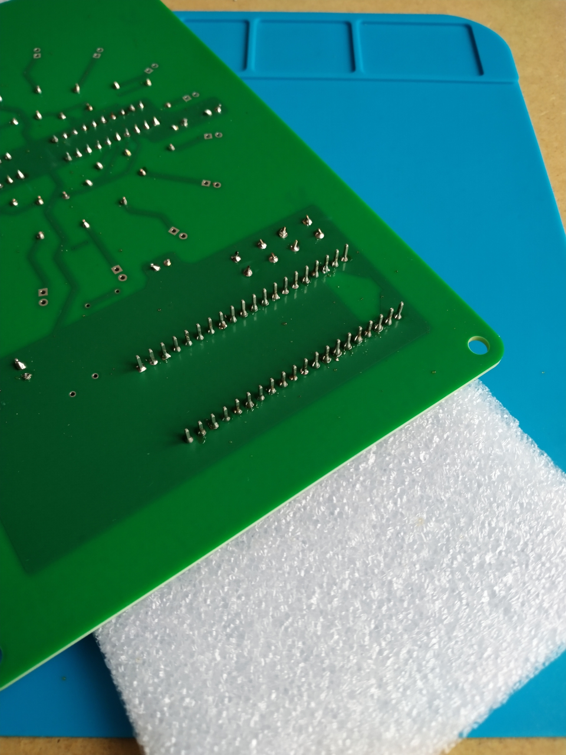
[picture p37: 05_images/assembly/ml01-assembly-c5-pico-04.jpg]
  
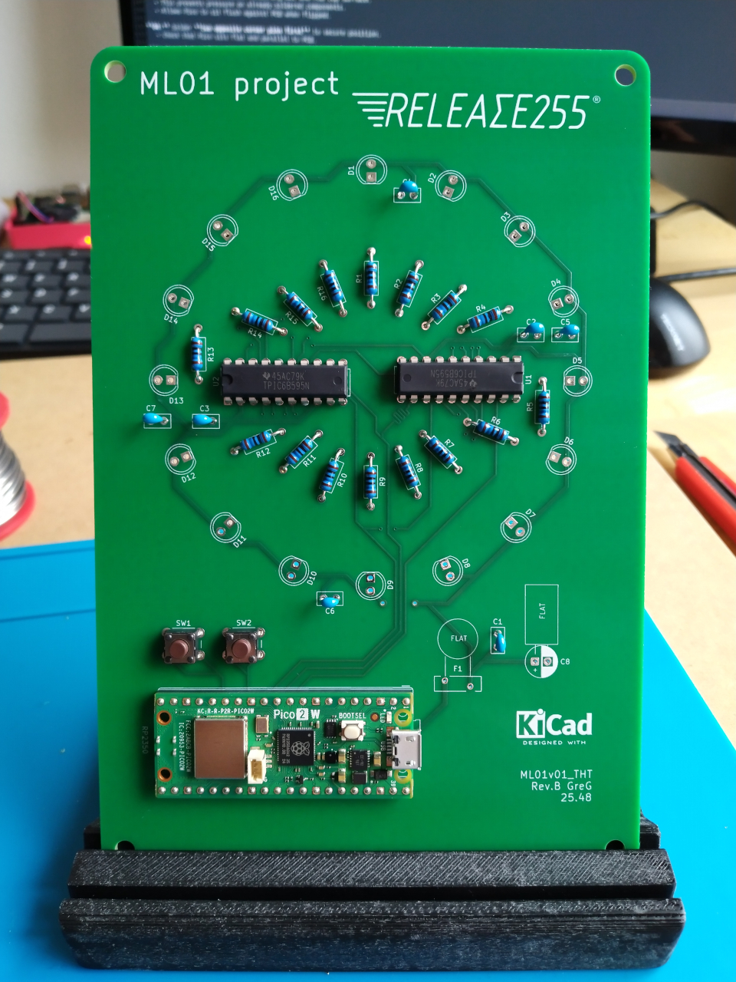
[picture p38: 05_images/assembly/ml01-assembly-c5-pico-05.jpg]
  
</p>

### C6. LEDs (16× Yellow 5mm)
**Difficulty level: tricky**  
<br>
⚠️ **Correct orientation and taking your time are essential for perfect and aesthetic alignment.**  
- **01.** Identify LED polarity on **each LED**:  
        - **Long lead = Anode (+)**<br>
        - **Short lead = Cathode (−)**<br>
        - **Flat edge of the LED = cathode side**<br>
        - **PCB silkscreen:** align the flat edge of the LED with the flat edge marking.
- **02.** Insert first LED (position D1) with correct polarity, then flip PCB on the soldering mat.
- **03.** Take the time to carefully check if the LED is properly seated and straighten it if necessary.  
        (Use foam if needed to ensure the PCB is perfectly horizontal).
- **04.** Gently solder without moving **one leg only** (anode recommended because it's more accessible from the outside).
- **05.** Repeat steps 01-04 for remaining 15 LEDs by depositing them symmetrically to be as stable as possible:  
        - Led D2, then D16, then D15, then D3, then D4, then D14, etc.<br>
        - Regularly trim the **soldered** leads if you want to free up space.
- **06.** Flip the PCB and check that all the LEDs are perfectly aligned and soldered in the correct orentiation.
- **07.** Flip again an finishes soldering all the cathode leads.
- **08.** Trim all LED leads, leaving ~2 mm protruding.

<p align="center">
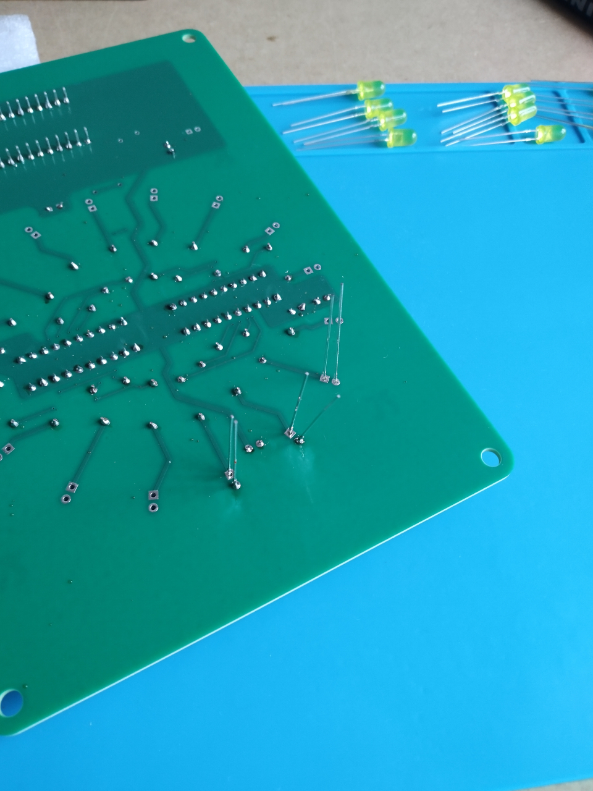
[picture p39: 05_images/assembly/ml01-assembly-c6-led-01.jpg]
  
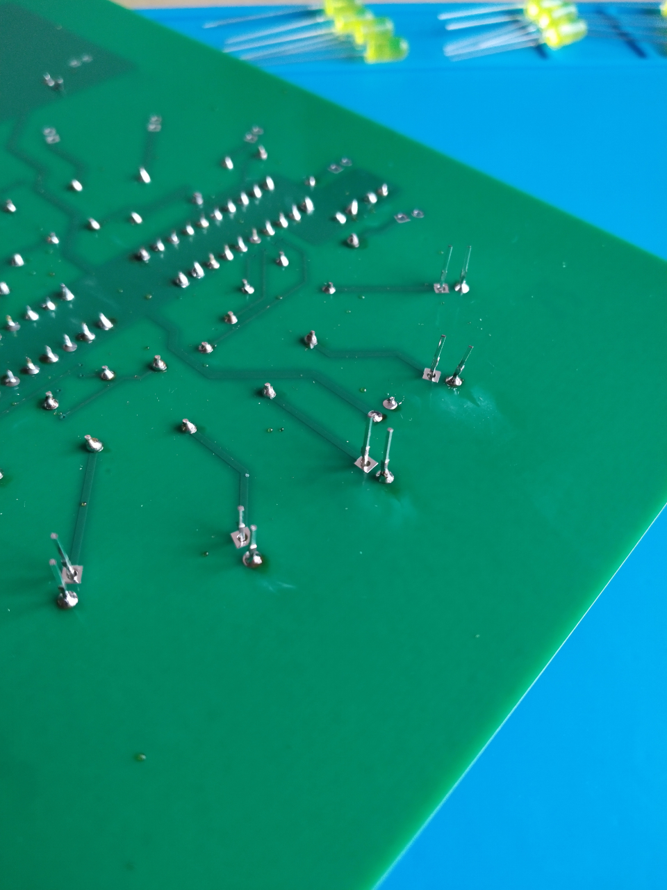
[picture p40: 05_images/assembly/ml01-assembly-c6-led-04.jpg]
  
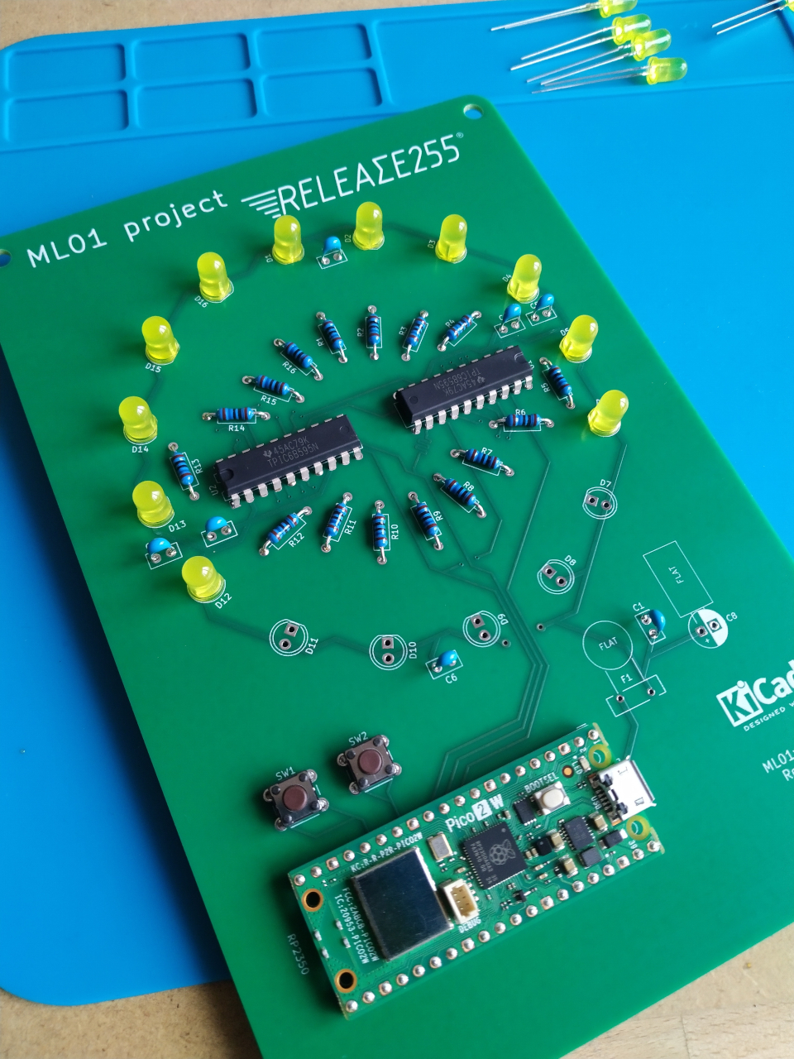
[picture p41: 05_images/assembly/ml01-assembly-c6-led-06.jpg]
  
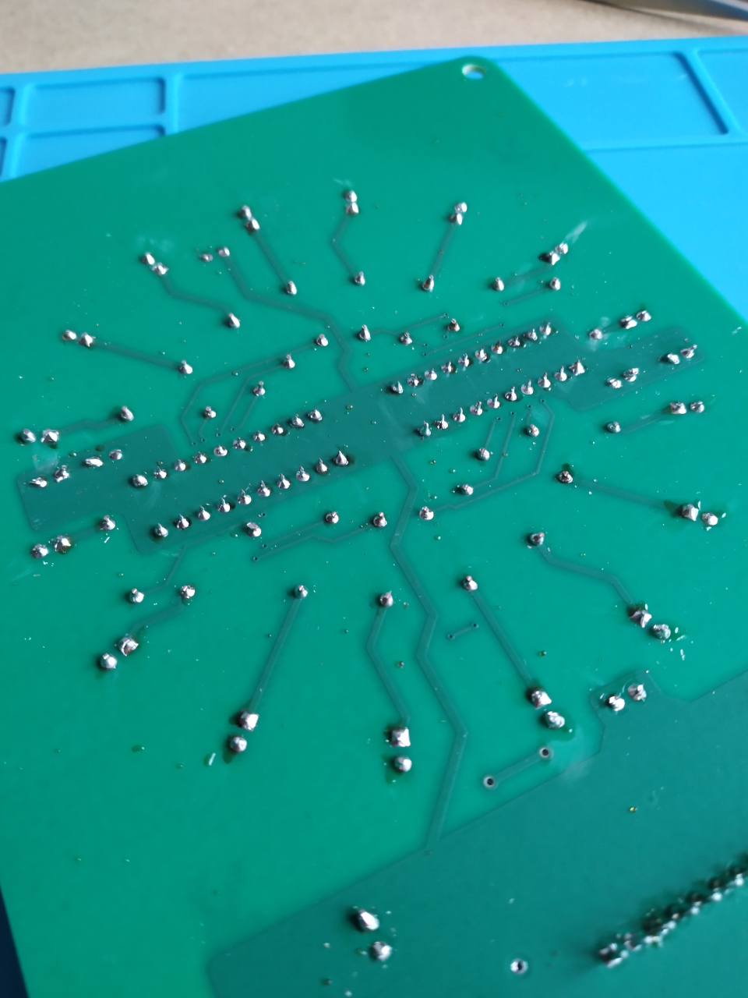
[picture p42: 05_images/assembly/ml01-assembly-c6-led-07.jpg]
  
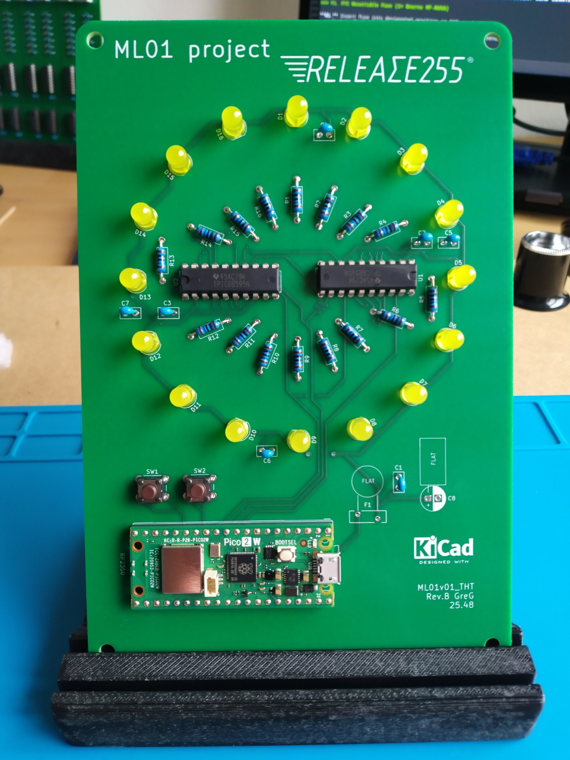
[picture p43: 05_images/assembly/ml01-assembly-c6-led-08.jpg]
  
</p>

### C7. PTC Resettable Fuse (1× Bourns MF-R050)
**Difficulty level: easy**
- **01.** Insert fuse into designated position on PCB:  
        - Fuse is **non-polarized** (orientation doesn't matter).<br>
        - **Leave leads long** (~10-15 mm from PCB surface before bending).
- **02.** Flip the PCB on the soldering mat an use foam to tackle the component to the PCB  
        (or use PCB stand for easier handling if you keep the components straight).
- **03.** Solder both fuse leads from underside.
- **04.** Trim 2 leads, leaving ~2 mm protruding.

<p align="center">
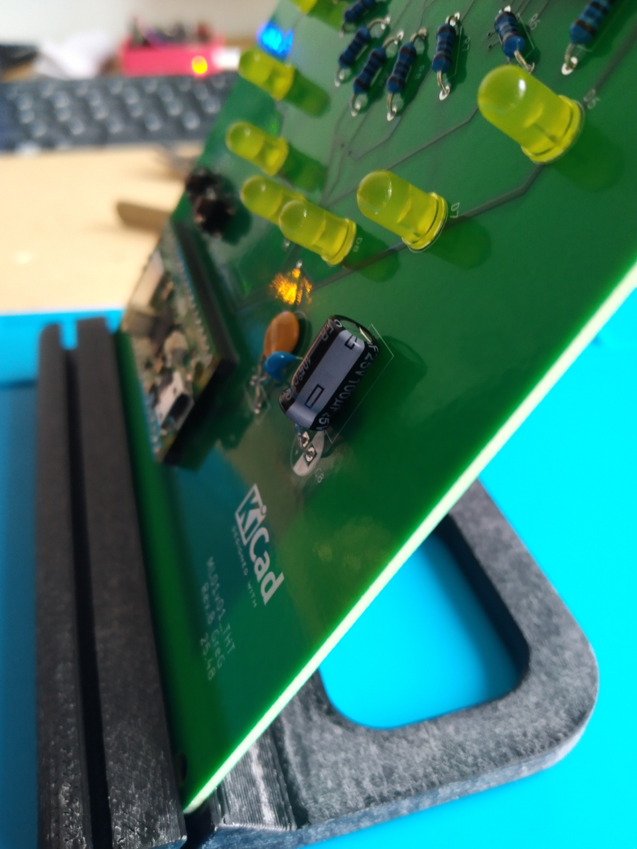
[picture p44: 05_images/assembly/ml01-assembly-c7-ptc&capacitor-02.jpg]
  
</p>

### C8. Electrolytic Capacitor (1× 100µF)
**Difficulty level: easy**  
<br>
⚠️ **Correct orientation is essential**
- **01.** Identify capacitor polarity:  
        - **Longer lead = Positive (+)**<br>
        - **Shorter lead = Negative (−)** and marked with stripe on capacitor body<br>
        - **PCB silkscreen:** "+" symbol indicated
- **02.** Insert capacitor with correct polarity.
- **03.** Flip the PCB on the soldering mat an use foam to tackle the component to the PCB.  
        (or use PCB stand for easier handling if you keep the components straight).
- **04.** Solder both capacitor leads from underside.
- **05.** Trim 2 leads, leaving ~2 mm protruding.
---

## D. POST-ASSEMBLY (FINISHING / INSPECTION / TESTING)
### D1. Lead Trimming
- **01.** Inspect all solder joints from the underside of the PCB.
- **02.** Trim any remaining long leads to ~2 mm from solder joint.
- **03.** Wear safety glasses during this step.

### D2. Flux Removal ⚠️ Follow manufacturer's instructions
- **01.** Apply flux remover spray to the underside of the PCB:  
        - Work in a well-ventilated area.<br>
        - Avoid contact with skin and eyes.
- **02.** Use a small brush to scrub away flux residue.
- **03.** Repeat these operations several times if necessary.

<p align="center">
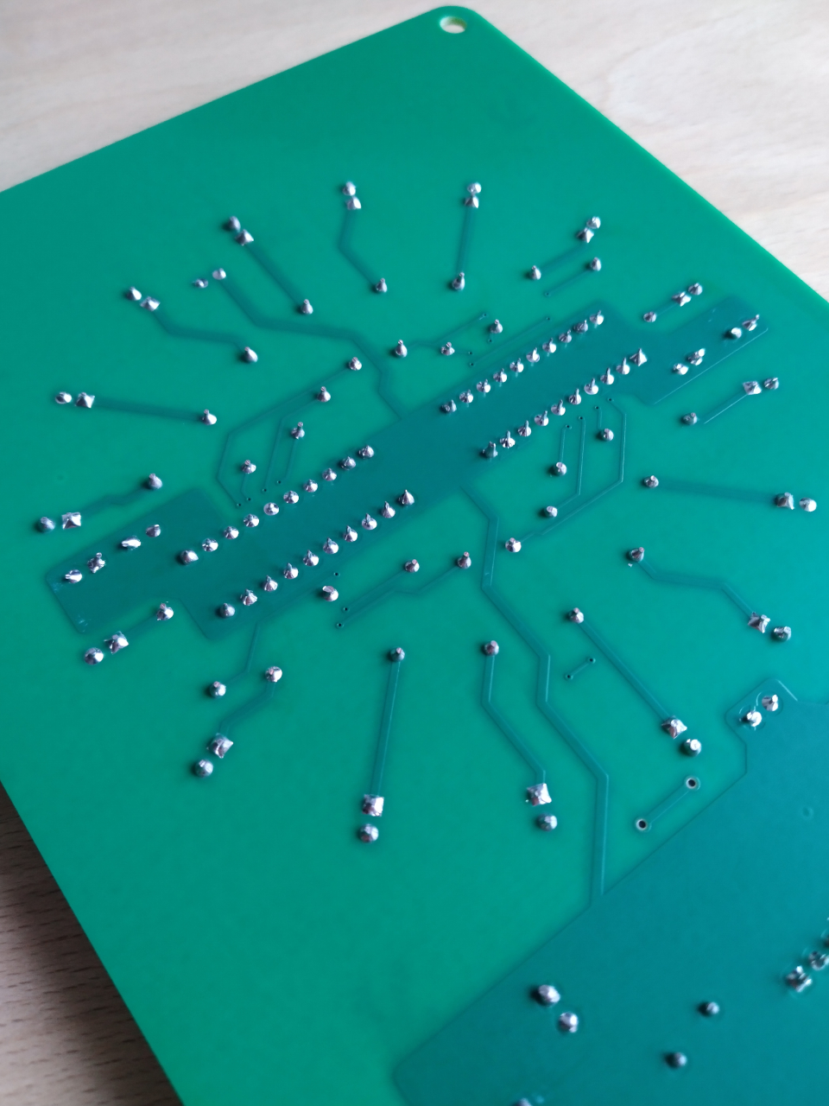
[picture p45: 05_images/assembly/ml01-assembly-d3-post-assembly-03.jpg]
  
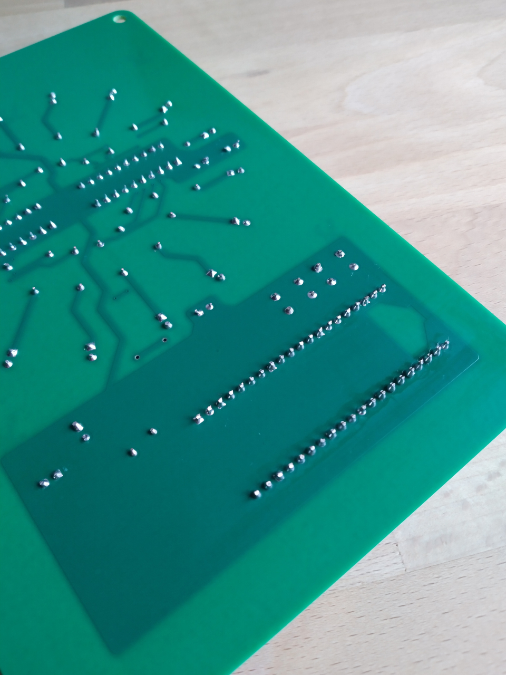
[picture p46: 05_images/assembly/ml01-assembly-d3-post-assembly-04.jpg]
  
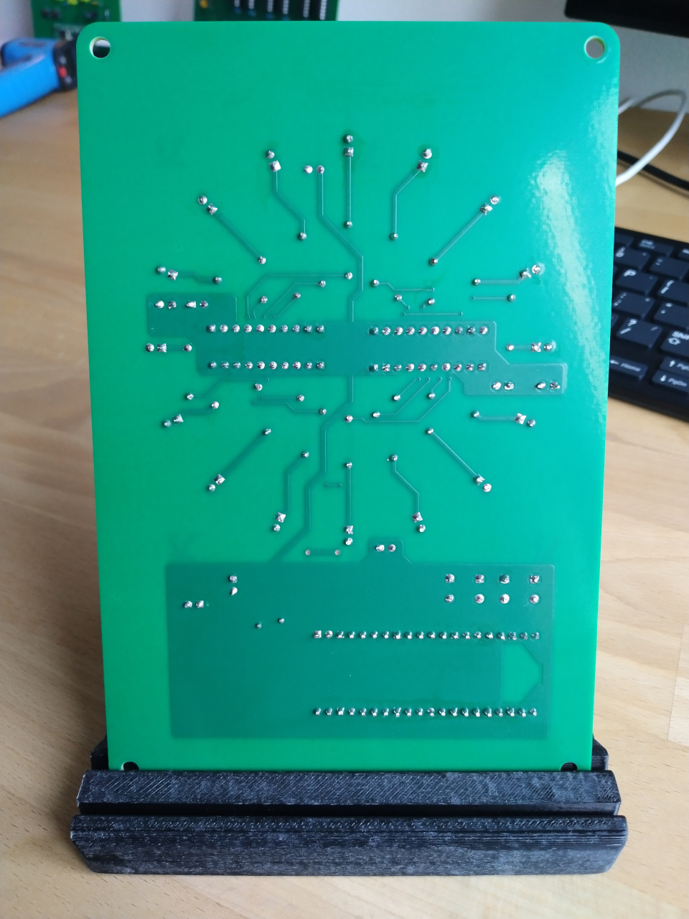
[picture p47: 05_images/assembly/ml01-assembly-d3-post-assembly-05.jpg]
  
</p>

### D3. Visual Inspection
- **01.** Examine all solder joints under good lighting (magnifying glass recommended):  
        ✓ Joints should be **shiny and cone-shaped** (not dull or grainy).<br>
        ✓ No **solder bridges** between adjacent pads.<br>
        ✓ No **cold solder joints** (cracked or irregular appearance).
- **02.** Check component orientation:  
        ✓ TPICs: Pin 1 correctly oriented<br>
        ✓ LEDs: All anodes (+) toward +5V rail<br>
        ✓ Electrolytic capacitor: Positive (+) lead correctly placed<br>
        ✓ Raspberry Pi Pico: Micro-USB connector oriented correctly
- **03.** Verify all components are fully seated and perpendicular to PCB.

### D4. Electrical Testing (Multimeter Required)
- **01.** Set multimeter to **continuity mode** (beep function).
- **02.** **Check for short circuits:**  
        ✓ Place one probe on +5V rail, other on GND: no continuity should be present (no beep).<br>
        ✓ If continuity detected, inspect for solder bridges.
- **03.** **Check +5V rail continuity:**  
        ✓ VSYS pin on Raspberry Pi Pico (pin 39)<br>
        ✓ VCC pins on both TPICs (pin 2)<br>
        ✓ LED anodes (all 16)
- **04.** **Check GND rail continuity:**  
        ✓ GND pins on Raspberry Pi Pico<br>
        ✓ GND pins on both TPICs (pins 10, 11, 19)

<p align="center">
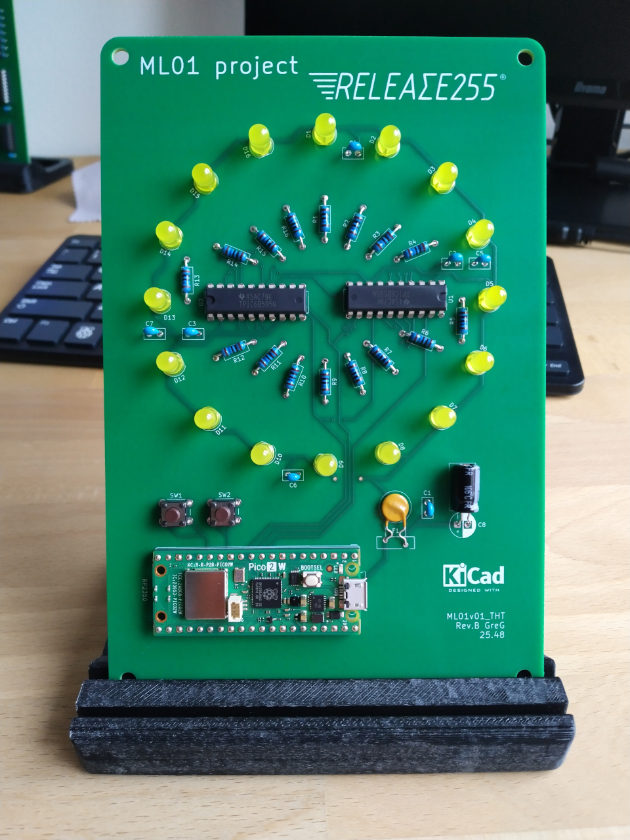
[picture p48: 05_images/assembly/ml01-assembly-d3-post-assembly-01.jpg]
  
</p>

### 🎉 CONGRATULATIONS 🎉 Your ML01 PCB assembly is complete but don't power on yet.
- **01.** Install 3D-printed stand to secure and display PCB.
- **02.** Refer to the next document 📖 [SETTINGS](../01_docs/ML01-settings.md) to flash the firmware and transfer programs to your pico.
---

*Revision date: 2026.01.26*<br>
© RELEASE255 | All rights reserved

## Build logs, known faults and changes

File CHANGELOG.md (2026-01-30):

# Changelog

All notable changes to the ML01 project will be documented in this file.

The format is based on [Keep a Changelog](https://keepachangelog.com/en/1.0.0/),
and this project adheres to [Semantic Versioning](https://semver.org/spec/v2.0.0.html).

## [Unreleased]

## [1.0.0] - 2026-01-30
### Added
- Initial public release of ML01 DIY LED Board
- Complete hardware documentation: specifications, assembly, settings, and usage guides
- Firmware with two operating modes (FULL and CHASE)
- Unlimited upgrades for personal use
- Web interface using Microdot framework
- WiFi connectivity via Raspberry Pi Pico 2W
- NTP synchronization for CHASE mode
- 3D printable PCB stand models
- Bill of Materials (BOM)
- Technical schematics and drawings
- Transparent costs allocation
- Multi-license structure (MIT, CC BY-SA, CC BY-NC-SA)

### Changed

### Deprecated

### Removed

### Fixed

### Security

[Unreleased]: https://github.com/RELEASE255/ML01_project/compare/v1.0.0...HEAD
[1.0.0]: https://github.com/RELEASE255/ML01_project/releases/tag/v1.0.0

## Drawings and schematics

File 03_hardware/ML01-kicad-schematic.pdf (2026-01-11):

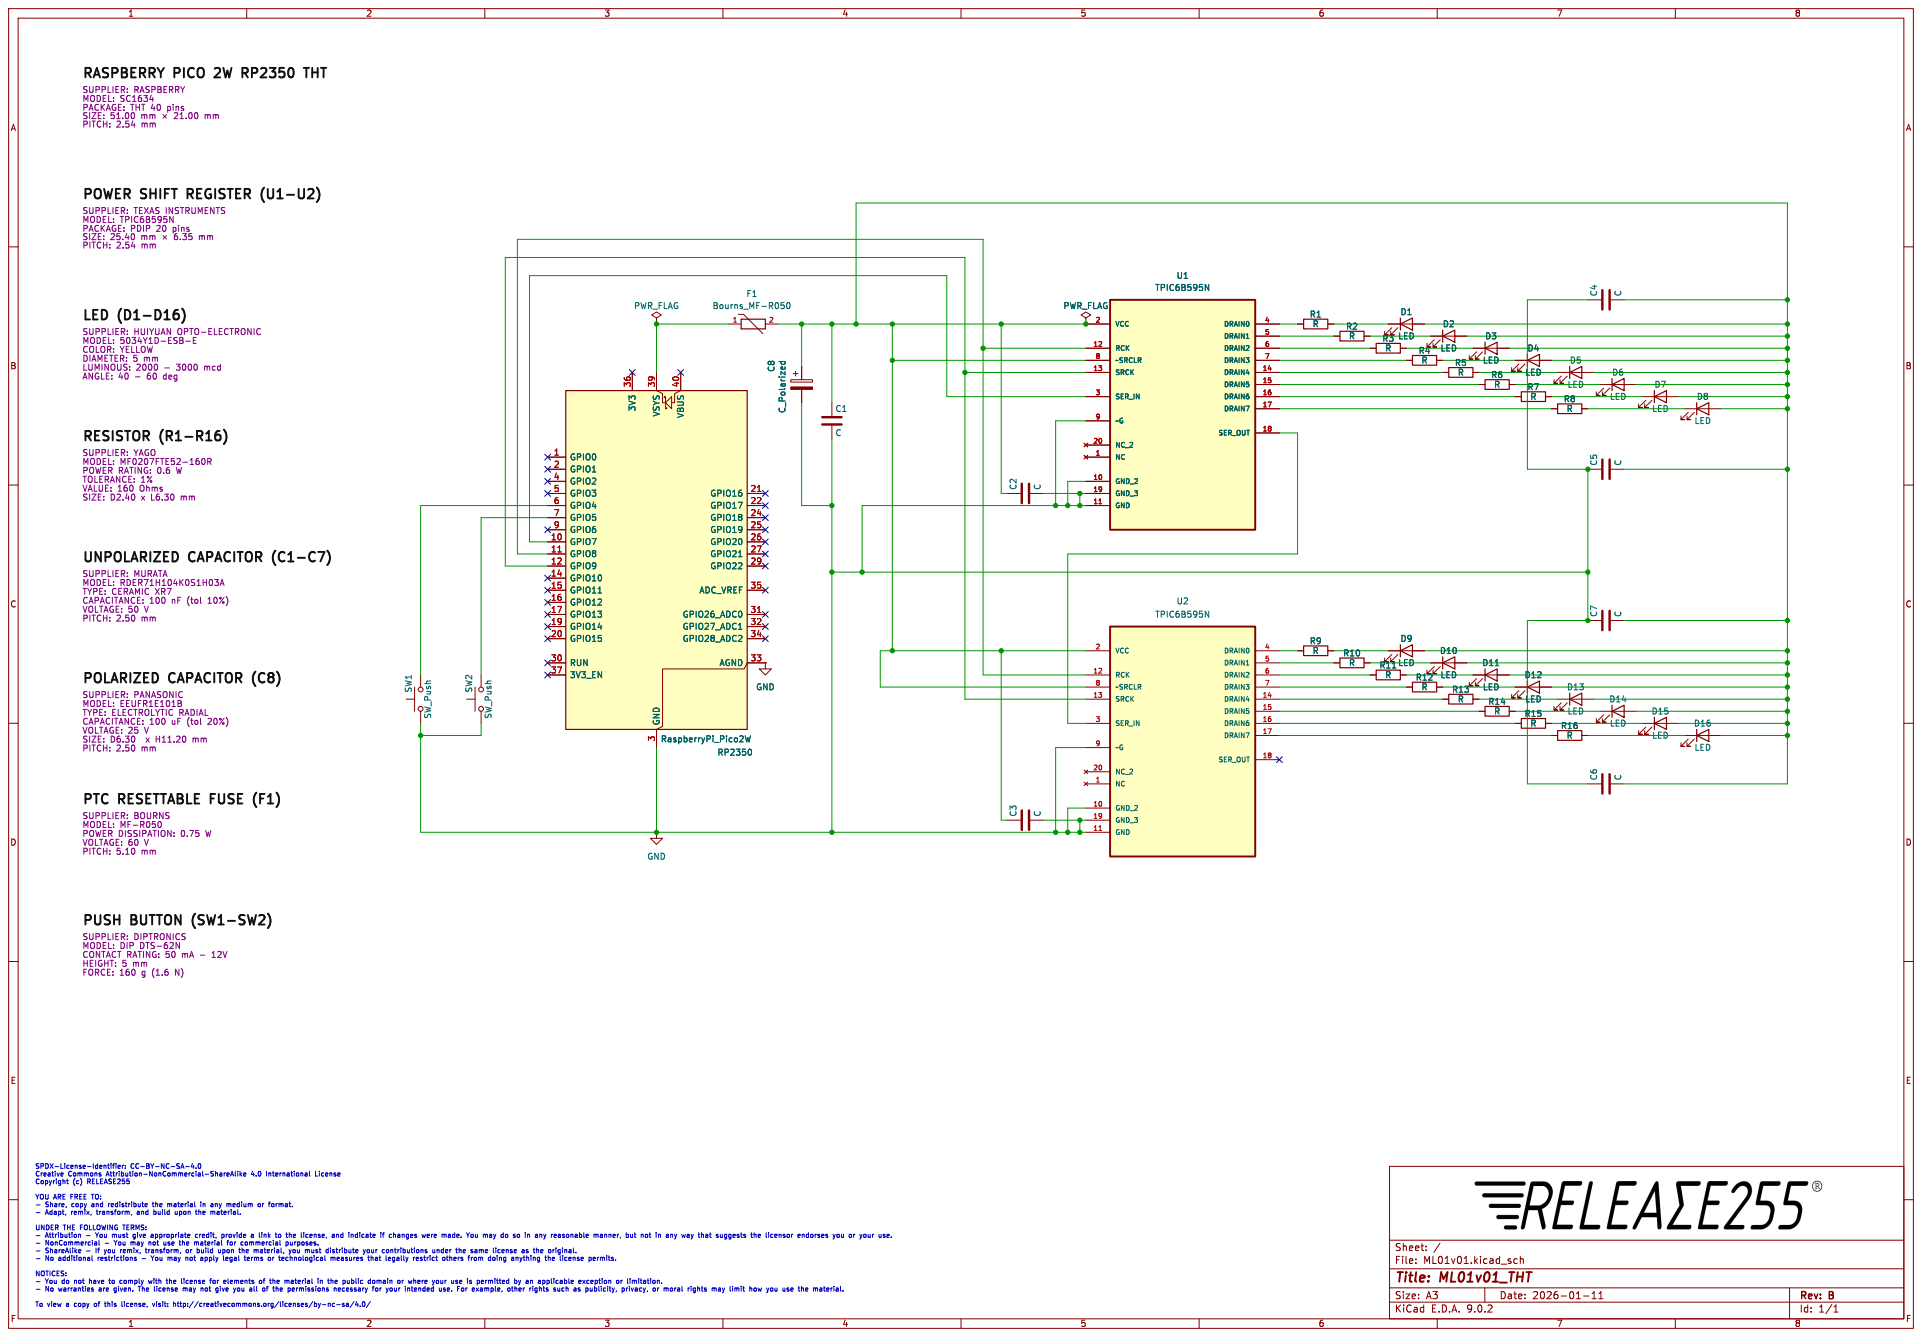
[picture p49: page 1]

PITCH: 2.54 mm PUSH BUTTON (SW1-SW2) SUPPLIER: DIPTRONICS MODEL: DIP DTS-62N

SUPPLIER: RASPBERRY MODEL: SC1634 PACKAGE: THT 40 pins SIZE: 51.00 mm þÿ×21.00 mm

POWER SHIFT REGISTER (U1-U2) SUPPLIER: TEXAS INSTRUMENTS MODEL: TPIC6B595N

PACKAGE: PDIP 20 pins SIZE: 25.40 mm þÿ×6.35 mm
PITCH: 2.54 mm

VALUE: 160 Ohms SIZE: D2.40 x L6.30 mm LED (D1-D16) SUPPLIER: HUIYUAN OPTO-ELECTRONIC MODEL: 5034Y1D-ESB-E COLOR: YELLOW

DIAMETER: 5 mm
LUMINOUS: 2000 - 3000 mcd ANGLE: 40 - 60 deg

PITCH: 2.50 mm RESISTOR (R1-R16) SUPPLIER: YAGO MODEL: MF0207FTE52-160R

PITCH: 5.10 mm UNPOLARIZED CAPACITOR (C1-C7) SUPPLIER: MURATA MODEL: RDER71H104K0S1H03A

TYPE: CERAMIC XR7 CAPACITANCE: 100 nF (tol 10%) VOLTAGE: 50 V

LED POLARIZED CAPACITOR (C8) SUPPLIER: PANASONIC MODEL: EEUFR1E101B

TYPE: ELECTROLYTIC RADIAL CAPACITANCE: 100 uF (tol 20%) VOLTAGE: 25 V

PTC RESETTABLE FUSE (F1) SUPPLIER: BOURNS MODEL: MF-R050 POWER DISSIPATION: 0.75 W

CONTACT RATING: 50 mA - 12V HEIGHT: 5 mm
FORCE: 160 g (1.6 N)

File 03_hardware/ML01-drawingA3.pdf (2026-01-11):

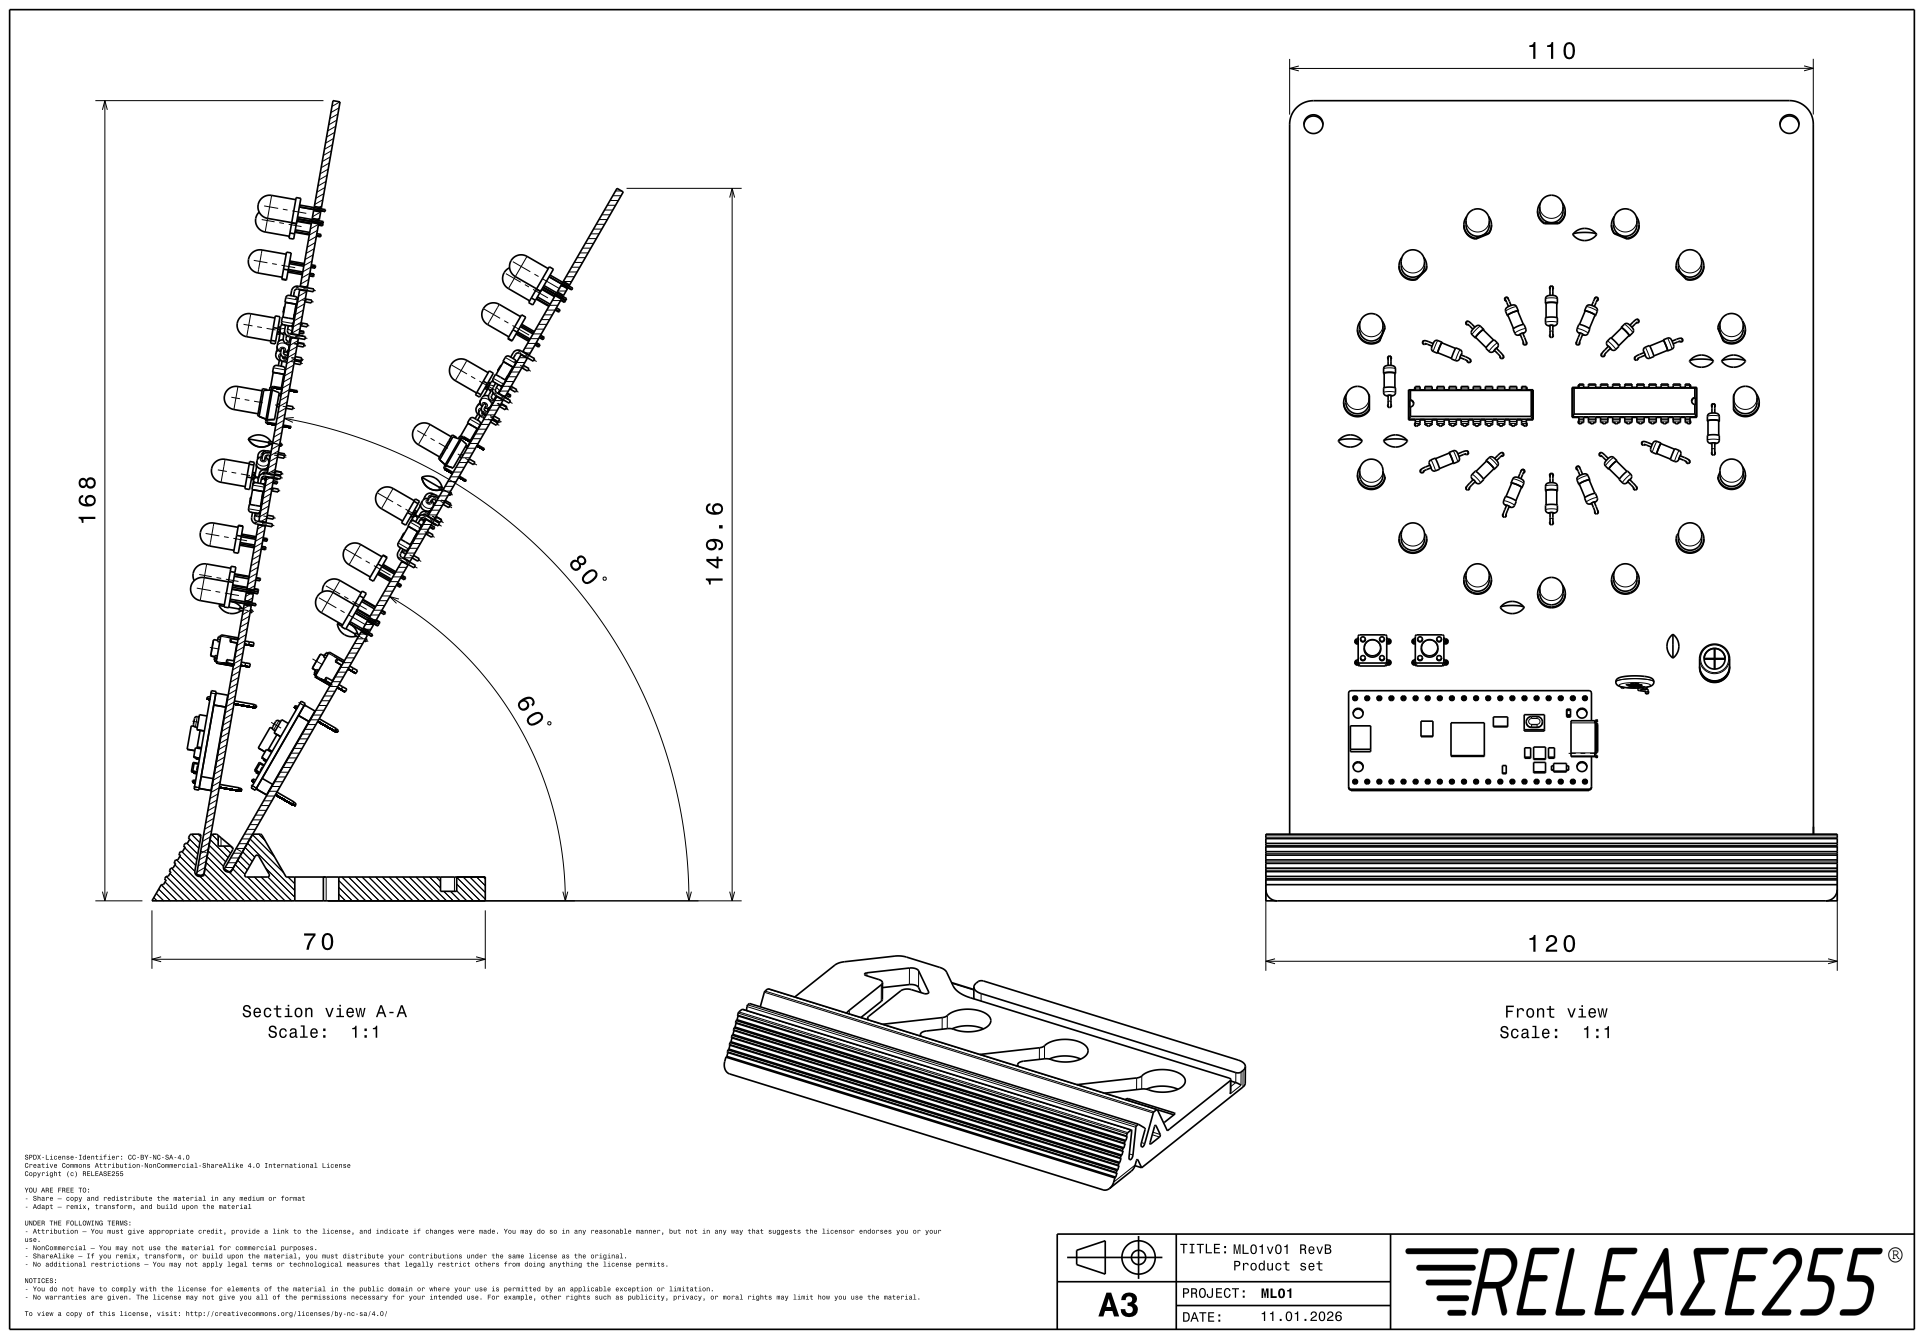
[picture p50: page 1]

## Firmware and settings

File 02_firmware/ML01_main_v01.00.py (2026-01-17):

#!/usr/bin/env python3
# -*- coding: utf-8 -*-
"""
ML01 project by RELEASE255 is a DIY LED board based on the Raspberry Pi Pico 2W microcontroller
Copyright (c) RELEASE255 | All rights reserved
MIT License
-----------------------------------------------------------------------------------------------
- FILE NAME: ML01_main_v01.00.py
- DESCRIPTION: Firmware written in MicroPython allowing the ML01 device to operate autonomously
- USE: rename to main.py for use with the index.html and microdot.py files on ML01 device
- HARDWARE COMPATIBILITY: PCB ML01v01 RevA & RevB
-----------------------------------------------------------------------------------------------
VERSION HISTORY:
- 2026.01.17 version 01.00 - Initial version
-----------------------------------------------------------------------------------------------
"""

import machine
import time
import utime
from machine import Pin
import gc
import network
import json
import _thread
from microdot import Microdot, Response
import ubinascii

# =============================================================================
# CONFIGURATION
# =============================================================================

# WiFi
WIFI_SSID = "yourSSID"  # SSID of the router to which the pico needs to connect
WIFI_PASSWORD = "yourPassword"  # Password of the router to which the pico needs to connect
WIFI_CHECK_INTERVAL = 600
WIFI_RECONNECT_ATTEMPTS = 2
WIFI_RECONNECT_DELAY = 20

# NTP
NTP_TIMEZONE_OFFSET = 1  # Choose your time zone here (UTC+1 = 1, UTC+2 = 2, etc.)

# Server
WEB_PORT = 80
DEVICE_NAME = "ML01 project by RELEASE255"

# GPIO
SER_DATA_PIN = 7
REGISTER_CLOCK_PIN = 8
SHIFT_CLOCK_PIN = 9
BUTTON1_PIN = 4
BUTTON2_PIN = 5

# Timing
CHASE_SPEED = 3.75  # Lighting duration of each LED in CHASE mode -> 60 minutes / 16 LED = 3.75 (in minutes)
CHASE_ANIMATION_SPEED = 0.05  # Duration of each LED's illumination in CHASE mode during the special hourly animation (in seconds)
CHASE_BLINK_SPEED = 1  # Blink speed for the special hourly animation finale (in seconds)
DEBOUNCE_TIME = 50
LONG_PRESS_TIME = 1500

# Authentication
AUTH_ENABLED = True
AUTH_USERNAME = "admin"  # Choose the login for remote control with the microdot server
AUTH_PASSWORD = "ML01secure!"  # Choose the password for remote control with the microdot server
AUTH_TOKEN = None

# Security
IP_WHITELIST_ENABLED = True
ALLOWED_IPS = [
    "192.168.x.xxx",  # Your computer
    "192.168.x.xxx",  # Your phone
    "192.168.x.xxx"   # Another device
]  # Edit above the IP addresses authorized for remote control with the microdot server
RATE_LIMIT_ENABLED = True
RATE_LIMIT_WINDOW = 60
RATE_LIMIT_MAX_REQUESTS = 30

# LED notifications
LED_NOTIFICATION_ENABLED = True
NEW_CONNECTION_BLINK_DURATION = 10

# Memory management
MEMORY_CHECK_INTERVAL = 1800  # 30 minutes
MEMORY_WARNING_THRESHOLD = 100000  # 100KB
MAX_LOG_ENTRIES = 1000

# =============================================================================
# GLOBALS
# =============================================================================

# Modes
MODE_OFF = 0
MODE_ON1 = 1
MODE_ON2 = 2

# State
current_mode = MODE_ON1
running = True
chase_position = 0
chase_first_update = False
last_hour_animation = -1  # Track last hour for animation trigger
web_server_running = False
restart_requested = False  # Flag for restart request
restart_request_time = 0   # Time when restart was requested

# Stats
program_start_time = time.time()
mode_on1_start_time = time.time()
total_on1_hours = 0.0

# Monitoring
last_wifi_check = 0
last_memory_check = 0
wifi_reconnecting = False

# Hardware
ser_data = None
reg_clock = None
shift_clock = None
button1 = None
button2 = None
onboard_led = None
temp_sensor = None
wlan = None
app = Microdot()

# Tracking
connected_ips = set()
led_blink_end_time = 0
request_counts = {}

# Logs
log_entries = []

# =============================================================================
# LOGGING
# =============================================================================

def add_log(message, log_type="INFO"):
    """Add log entry"""
    global log_entries
    timestamp = format_datetime(time.time())
    log_entries.append({
        "timestamp": timestamp,
        "type": log_type,
        "message": message
    })
    
    if len(log_entries) > MAX_LOG_ENTRIES:
        log_entries = log_entries[-MAX_LOG_ENTRIES:]
        gc.collect()
    
    if len(log_entries) % 50 == 0:
        gc.collect()
    
    print(f"[{log_type}] {message}")

# =============================================================================
# MEMORY MANAGEMENT
# =============================================================================

def check_memory():
    """Check and log memory status"""
    global last_memory_check
    
    current_time = time.time()
    if current_time - last_memory_check < MEMORY_CHECK_INTERVAL:
        return
    
    last_memory_check = current_time
    gc.collect()
    free = gc.mem_free()
    
    print(f"[MEMORY] Periodic check - Free: {free} bytes ({len(log_entries)} logs)")
    
    if free < MEMORY_WARNING_THRESHOLD:
        print(f"[MEMORY] WARNING: Low memory! Cleaning up...")
        add_log(f"Low memory: {free} bytes - reducing logs", "SYSTEM")
        log_entries[:] = log_entries[-500:]
        gc.collect()
        print(f"[MEMORY] After cleanup: {gc.mem_free()} bytes")

# =============================================================================
# WIFI
# =============================================================================

def connect_wifi():
    """Connect to WiFi"""
    global wlan, onboard_led
    
    print("Connecting to WiFi...")
    
    if wlan is None:
        wlan = network.WLAN(network.STA_IF)
    
    wlan.active(True)
    
    if LED_NOTIFICATION_ENABLED and onboard_led is None:
        onboard_led = Pin("LED", Pin.OUT)
        onboard_led.value(0)
    
    if not wlan.isconnected():
        wlan.connect(WIFI_SSID, WIFI_PASSWORD)
        timeout = 200
        
        while not wlan.isconnected() and timeout > 0:
            if timeout % 20 == 0:
                print(".", end="")
            time.sleep_ms(100)
            timeout -= 1
        
        print()
        
        if wlan.isconnected():
            ip_info = wlan.ifconfig()
            add_log(f"WiFi connected - IP: {ip_info[0]}", "WIFI")
            print(f"IP: {ip_info[0]}")
            
            if LED_NOTIFICATION_ENABLED and onboard_led:
                onboard_led.value(1)
            
            sync_time_ntp()
            return True
        else:
            if not wifi_reconnecting:
                add_log("WiFi connection failed", "ERROR")
            if LED_NOTIFICATION_ENABLED and onboard_led:
                onboard_led.value(0)
            return False
    else:
        if LED_NOTIFICATION_ENABLED and onboard_led:
            onboard_led.value(1)
        sync_time_ntp()
        return True

def check_wifi_connection():
    """Monitor WiFi and reconnect if needed"""
    global wlan, wifi_reconnecting, last_wifi_check
    
    current_time = time.time()
    
    if current_time - last_wifi_check < WIFI_CHECK_INTERVAL:
        return
    
    last_wifi_check = current_time
    
    if wifi_reconnecting:
        return
    
    if wlan is None or not wlan.isconnected():
        add_log("WiFi lost! Reconnecting...", "WIFI")
        print("\n⚠️  WiFi lost! Reconnecting...")
        wifi_reconnecting = True
        
        if LED_NOTIFICATION_ENABLED and onboard_led:
            onboard_led.value(0)
        
        gc.collect()
        
        for attempt in range(WIFI_RECONNECT_ATTEMPTS):
            print(f"Attempt {attempt + 1}/{WIFI_RECONNECT_ATTEMPTS}...")
            
            if connect_wifi():
                add_log("WiFi reconnected!", "WIFI")
                print("✓ Reconnected!")
                wifi_reconnecting = False
                return
            
            if attempt < WIFI_RECONNECT_ATTEMPTS - 1:
                time.sleep(WIFI_RECONNECT_DELAY)
        
        add_log("WiFi reconnection failed", "ERROR")
        print("✗ Reconnection failed")
        wifi_reconnecting = False

def sync_time_ntp():
    """Sync time with NTP"""
    try:
        import ntptime
        add_log("Syncing time with NTP...", "SYSTEM")
        ntptime.settime()
        
        utc_time = time.time()
        local_time = utc_time + (NTP_TIMEZONE_OFFSET * 3600)
        tm = time.localtime(local_time)
        machine.RTC().datetime((tm[0], tm[1], tm[2], tm[6], tm[3], tm[4], tm[5], 0))
        
        add_log(f"Time synced: {format_datetime(time.time())}", "SYSTEM")
        print(f"✓ Time synced (UTC+{NTP_TIMEZONE_OFFSET})")
        return True
    except Exception as e:
        add_log(f"NTP sync failed: {str(e)}", "ERROR")
        return False

# =============================================================================
# HARDWARE
# =============================================================================

def init_gpio():
    """Initialize GPIO"""
    global ser_data, reg_clock, shift_clock, button1, button2, temp_sensor
    
    print("Initializing GPIO...")
    ser_data = Pin(SER_DATA_PIN, Pin.OUT)
    reg_clock = Pin(REGISTER_CLOCK_PIN, Pin.OUT)
    shift_clock = Pin(SHIFT_CLOCK_PIN, Pin.OUT)
    button1 = Pin(BUTTON1_PIN, Pin.IN, Pin.PULL_UP)
    button2 = Pin(BUTTON2_PIN, Pin.IN, Pin.PULL_UP)
    temp_sensor = machine.ADC(4)
    
    ser_data.value(0)
    reg_clock.value(0)
    shift_clock.value(0)
    print("GPIO initialized")

def read_pico_temperature():
    """Read Pico internal temperature in Celsius"""
    try:
        if temp_sensor is None:
            return None
        
        # Read ADC value
        adc_value = temp_sensor.read_u16()
        
        # Convert to voltage (3.3V reference)
        voltage = adc_value * 3.3 / 65535
        
        # Convert to temperature (formula from Pico datasheet)
        # T = 27 - (ADC_voltage - 0.706)/0.001721
        temperature = 27 - (voltage - 0.706) / 0.001721
        
        return round(temperature, 1)
    except Exception as e:
        print(f"[ERROR] Temperature read failed: {e}")
        return None

def cleanup_gpio():
    """Cleanup GPIO"""
    shift_out_16bit(0x00, 0x00)
    if ser_data:
        ser_data.init(Pin.IN)
    if reg_clock:
        reg_clock.init(Pin.IN)
    if shift_clock:
        shift_clock.init(Pin.IN)
    if onboard_led:
        onboard_led.value(0)
    print("GPIO cleaned")

def shift_out_16bit(data_low, data_high):
    """Send 16-bit data to shift registers"""
    for i in range(7, -1, -1):
        ser_data.value((data_high >> i) & 1)
        shift_clock.value(1)
        utime.sleep_us(1)
        shift_clock.value(0)
        utime.sleep_us(1)
    
    for i in range(7, -1, -1):
        ser_data.value((data_low >> i) & 1)
        shift_clock.value(1)
        utime.sleep_us(1)
        shift_clock.value(0)
        utime.sleep_us(1)
    
    reg_clock.value(1)
    utime.sleep_us(1)
    reg_clock.value(0)

# =============================================================================
# LED CONTROL
# =============================================================================

def set_mode_off():
    """Turn off all LEDs"""
    shift_out_16bit(0x00, 0x00)

def set_mode_on1():
    """Turn on all LEDs"""
    shift_out_16bit(0xFF, 0xFF)

def play_chase_animation(target_led):
    """
    Play LED chase animation sequence
    - Full cycle: LED 1 to 16
    - Partial cycle: LED 1 to target_led
    target_led: final LED position (0-15)
    """
    print(f"[CHASE] Starting animation to LED {target_led + 1}")
    
    # Cycle 1: Full animation LED 1 to 16
    for i in range(16):
        if i < 8:
            data_low = 1 << i
            data_high = 0x00
        else:
            data_low = 0x00
            data_high = 1 << (i - 8)
        shift_out_16bit(data_low, data_high)
        time.sleep(CHASE_ANIMATION_SPEED)
    
    # Cycle 2: Partial animation LED 1 to target_led
    for i in range(target_led + 1):
        if i < 8:
            data_low = 1 << i
            data_high = 0x00
        else:
            data_low = 0x00
            data_high = 1 << (i - 8)
        shift_out_16bit(data_low, data_high)
        time.sleep(CHASE_ANIMATION_SPEED)
    
    print(f"[CHASE] Animation complete, LED {target_led + 1} active")

def play_hourly_animation():
    """
    Play full LED chase animation at XX:00:00
    3 full cycles (LED 1 to 16), then 3 rapid blinks of all LEDs, stops at LED 1
    """
    print("[CHASE] Hourly animation triggered - 3 cycles + blinks")
    
    # 3 full cycles: LED 1 to 16
    for cycle in range(3):
        print(f"[CHASE] Cycle {cycle + 1}/3")
        for i in range(16):
            if i < 8:
                data_low = 1 << i
                data_high = 0x00
            else:
                data_low = 0x00
                data_high = 1 << (i - 8)
            shift_out_16bit(data_low, data_high)
            time.sleep(CHASE_ANIMATION_SPEED)
    
    # 3 rapid blinks of all LEDs
    print("[CHASE] Final blinks (3x)")
    for blink in range(3):
        # All LEDs ON
        shift_out_16bit(0xFF, 0xFF)
        time.sleep(CHASE_BLINK_SPEED)
        # All LEDs OFF
        shift_out_16bit(0x00, 0x00)
        time.sleep(CHASE_BLINK_SPEED)
    
    # Final position: LED 1 (position 0)
    shift_out_16bit(0x01, 0x00)
    print("[CHASE] Hourly animation complete, LED 1 active")

def update_chase_mode():
    """Update chase effect with animations"""
    global chase_position, chase_first_update, last_hour_animation
    
    # Get current time info
    current_time = time.time()
    tm = time.localtime(current_time)
    current_hour = tm[3]
    current_minute = tm[4]
    current_second = tm[5]
    
    # Check for hourly animation (at XX:00:00)
    if current_minute == 0 and current_second == 0 and last_hour_animation != current_hour:
        last_hour_animation = current_hour
        play_hourly_animation()
        chase_position = 0  # LED 1 position
        return
    
    # Get LED position based on current time
    led_position = get_current_led_from_time()
    
    # Check if it's the first update (mode just started)
    if chase_first_update:
        chase_first_update = False
        play_chase_animation(led_position)
        chase_position = led_position
        return
    
    # Normal update: only change if position changed
    if led_position != chase_position:
        chase_position = led_position
        
        if chase_position < 8:
            data_low = 1 << chase_position
            data_high = 0x00
        else:
            data_low = 0x00
            data_high = 1 << (chase_position - 8)
        
        shift_out_16bit(data_low, data_high)

def get_current_led_from_time():
    """Calculate LED position from time"""
    current_time = time.time()
    tm = time.localtime(current_time)
    minutes = tm[4]
    seconds = tm[5]
    fractional = current_time - int(current_time)
    
    total_minutes = minutes + (seconds / 60.0) + (fractional / 60.0)
    led_position = int(total_minutes / CHASE_SPEED)
    
    if led_position >= 16:
        led_position = 0
    
    return led_position

def manage_onboard_led():
    """Manage onboard LED"""
    global led_blink_end_time
    
    if not LED_NOTIFICATION_ENABLED or not onboard_led:
        return
    
    current_time = time.time()
    
    if current_time < led_blink_end_time:
        blink_state = int(current_time * 5) % 2
        onboard_led.value(blink_state)
    else:
        if wlan and wlan.isconnected():
            onboard_led.value(1)
        else:
            onboard_led.value(0)

def trigger_new_connection():
    """Trigger LED notification"""
    global led_blink_end_time
    if LED_NOTIFICATION_ENABLED:
        led_blink_end_time = time.time() + NEW_CONNECTION_BLINK_DURATION

# =============================================================================
# BUTTONS
# =============================================================================

def check_button_press(button):
    """Check button press type"""
    if not button.value():
        press_start = time.ticks_ms()
        while not button.value():
            if time.ticks_diff(time.ticks_ms(), press_start) > LONG_PRESS_TIME:
                return "long"
            time.sleep_ms(10)
        time.sleep_ms(DEBOUNCE_TIME)
        return "short"
    return None

def handle_button1():
    """Handle button 1 - mode switching/exit"""
    global running
    press = check_button_press(button1)
    if press == "long":
        print("\nButton 1 long press - shutting down...")
        running = False
    elif press == "short":
        change_mode_next()

def handle_button2():
    """Handle button 2 - manual restart"""
    press = check_button_press(button2)
    if press == "long":
        print("\nButton 2 long press - restarting...")
        perform_restart()

def change_mode_next():
    """Cycle to next mode"""
    global current_mode, mode_on1_start_time, total_on1_hours, chase_position, chase_first_update, last_hour_animation
    
    old_mode = current_mode
    
    if current_mode == MODE_ON1:
        current_mode = MODE_ON2
        if mode_on1_start_time:
            total_on1_hours += (time.time() - mode_on1_start_time) / 3600
            mode_on1_start_time = None
    elif current_mode == MODE_ON2:
        current_mode = MODE_OFF
    else:
        current_mode = MODE_ON1
        mode_on1_start_time = time.time()
    
    if current_mode == MODE_ON2:
        chase_position = get_current_led_from_time()
        chase_first_update = True
        last_hour_animation = -1  # Reset hourly animation tracker
    
    add_log(f"Mode: {get_mode_name(old_mode)} -> {get_mode_name(current_mode)}", "MODE")

def set_mode(mode):
    """Set specific mode (API)"""
    global current_mode, mode_on1_start_time, total_on1_hours, chase_position, chase_first_update, last_hour_animation
    
    if mode not in [MODE_OFF, MODE_ON1, MODE_ON2]:
        return False
    
    old_mode = current_mode
    
    if current_mode == MODE_ON1 and mode != MODE_ON1:
        if mode_on1_start_time:
            total_on1_hours += (time.time() - mode_on1_start_time) / 3600
            mode_on1_start_time = None
    
    if mode == MODE_ON1 and current_mode != MODE_ON1:
        mode_on1_start_time = time.time()
    
    current_mode = mode
    
    if mode == MODE_ON2:
        chase_position = get_current_led_from_time()
        chase_first_update = True
        last_hour_animation = -1  # Reset hourly animation tracker
    
    add_log(f"Mode: {get_mode_name(old_mode)} -> {get_mode_name(current_mode)}", "MODE")
    return True

def get_mode_name(mode):
    """Get mode name"""
    if mode == MODE_OFF:
        return "OFF"
    elif mode == MODE_ON1:
        return "ON"
    elif mode == MODE_ON2:
        return "CHASE"
    return "Unknown"

def perform_restart():
    """Restart system"""
    add_log("Manual restart initiated", "SYSTEM")
    print("\n" + "="*50)
    print("RESTARTING...")
    print("="*50)
    time.sleep(2)
    machine.reset()

# =============================================================================
# STATISTICS
# =============================================================================

def calculate_on1_hours():
    """Calculate total ON1 hours"""
    hours = total_on1_hours
    if mode_on1_start_time:
        hours += (time.time() - mode_on1_start_time) / 3600
    return hours

def format_duration(hours):
    """Format duration"""
    total_seconds = int(hours * 3600)
    days = total_seconds // 86400
    remaining = total_seconds % 86400
    hours_part = remaining // 3600
    minutes = (remaining % 3600) // 60
    
    if days > 0:
        return f"{days}d {hours_part}h {minutes}m"
    elif hours_part > 0:
        return f"{hours_part}h {minutes}m"
    return f"{minutes}m"

def format_datetime(timestamp):
    """Format timestamp"""
    tm = time.localtime(timestamp)
    return "{:02d}/{:02d}/{:04d} - {:02d}:{:02d}:{:02d}".format(
        tm[2], tm[1], tm[0], tm[3], tm[4], tm[5]
    )

def get_system_stats():
    """Get system statistics"""
    on1_hours = calculate_on1_hours()
    uptime = (time.time() - program_start_time) / 3600
    pico_temp = read_pico_temperature()
    
    # Determine temperature status
    temp_status = "Normal"
    if pico_temp is not None:
        if pico_temp > 70:
            temp_status = "Critical"
        elif pico_temp > 60:
            temp_status = "High"
        elif pico_temp > 50:
            temp_status = "Warm"
            
    # Format temperature string
    temp_str = "{}°C".format(pico_temp) if pico_temp is not None else "N/A"
   
    return {
        "device_name": DEVICE_NAME,
        "current_mode": get_mode_name(current_mode),
        "program_start": format_datetime(program_start_time),
        "uptime": format_duration(uptime),
        "total_on1_time": format_duration(on1_hours),
        "last_update": format_datetime(time.time()),
        "chase_position": chase_position if current_mode == MODE_ON2 else "N/A",
        "total_leds": 16,
        "wifi_status": "Connected" if (wlan and wlan.isconnected()) else "Disconnected",
        "pico_temperature": temp_str,
        "temp_status": temp_status
    }

def get_network_info():
    """Get network info"""
    if wlan and wlan.isconnected():
        ip_info = wlan.ifconfig()
        return {
            "connected": True,
            "ssid": WIFI_SSID,
            "ip": ip_info[0],
            "subnet": ip_info[1],
            "gateway": ip_info[2],
            "dns": ip_info[3]
        }
    return {
        "connected": False,
        "ssid": WIFI_SSID,
        "ip": "Not connected"
    }

# =============================================================================
# SECURITY
# =============================================================================
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

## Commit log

2025-11-29 Update and rename aseembly_guide.pdf to assembly_guide.pdf
2026-01-10 Update and rename LICENSE_bom.md to LICENSE-bom.md

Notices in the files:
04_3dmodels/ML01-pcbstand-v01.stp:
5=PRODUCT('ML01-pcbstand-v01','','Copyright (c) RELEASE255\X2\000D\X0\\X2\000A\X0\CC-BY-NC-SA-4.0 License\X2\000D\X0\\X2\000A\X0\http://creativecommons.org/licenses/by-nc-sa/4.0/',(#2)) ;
